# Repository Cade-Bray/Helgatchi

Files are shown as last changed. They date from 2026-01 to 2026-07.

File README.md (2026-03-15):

# Helgatchi
Handheld BLE + WiFi Hunter

## What is it?
A portable, hand-held BLE beacon and WiFi AP scanner/hunter, with built-in alerting, 1.69” full-color screen, and external SMA-RP antenna all powered by the XIAO ESP32-S3. 

The Helgatchi will passively scan for BLE devices and WiFi SSIDs/APs, and alert when specific Manufacturers, naming schemes, or services are discovered. 

It can be configured to alert anything you want, such as:
- Flock technology
- AXON technology
- Wearable health devices
- Any specific device
- Hidden WiFi/Bluetooth cameras

## Key Features
- Enclosed, portable, battery powered handheld rechargeable BLE and WiFi scanner and hunter that can live in your pocket.
- Passively scans for beacons in the background in-between sleeping, and actively scans when an alert is triggered.
- Powered by the XIAO ESP32-S3
- 6 RGB LEDs
- 1.69" rounded screen
- Vibration motor for alerts
- You can change
  - Color scheme
  - Alert settings
    - Vibrate
    - LEDs
    - Screen Wake
  - Scan settings
    - Sleep duration
    - Scan duration
  - Rules for alerts
    - MAC address (BLE, WiFi)
    - Manufacturer (BLE, WiFi OUI)
    - Device name (BLE name, WiFi SSID)
    - Service (BLE)

## Specifications

| Spec | Info 	|
|---	|---	|
| MCU 	| XIAO ESP32-S3 	|
| Flash 	| 8MB 	|
| Battery  	| 800mAh - 1200mAh 3.7v LiPo 	|
| Screen 	| Waveshare 1.69” LCD - 240p × 280p 	|
| Firmware 	| platform.io + Arduino 	|
| Software 	| Graphics: LVGL BLE: NimBLE LEDs: FastLED 	|
| Antenna  	| XIAO -> u.FL > back PCB > SMA-RP > 2.4Ghz antenna 	|
| Size 	| Width: 50mm Length: 80mm Height: TBD 	|

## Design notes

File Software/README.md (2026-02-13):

# Building and deploying (old code)
You will need
* VSCode
  * PlatformIO VSCode extension
* ESP32S3
* SPI connected screen

1. Clone the repository
2. Navigate into the `Helgatchi/Software/Helgatchi Core` directory
3. Initialize Platform.IO project (PIO -> Open Project -> Navigate to Helgatchi Core folder)
4. Build the code, will probably take a while to set up (Project tasts -> Build)
5. Build the filesystem (Project tasks -> Build Filesystem Image)
6. Plug in your ESP
7. Erase Flash
8. Upload Filesystem Image
9. Upload and Monitor

This should flash the ESP with filesystem and the code, and the serial monitor should output what the device is doing.

# Building and deploying (LVGL)
TODO

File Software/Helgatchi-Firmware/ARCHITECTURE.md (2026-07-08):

# Architecture

This document describes the firmware as it actually exists. The earlier
revision was design-only; this one tracks what's been built, the conventions
in use, and the footguns that have already cost real time.

---

## Big picture

```
                                 +---------------------+
        physical buttons ------> |                     |
        USB SOF / VSENSE  ------>|     HAL (g_hal)     |---> LCD (LovyanGFX)
        backlight / vibe / LEDs <|                     |---> WS2812 LEDs
                                 +---------------------+
                                            |
                                       posts EV_BTN_*, EV_UI_ACTIVITY
                                            v
                              +---------------------------+
                              |   EventBus (g_bus)        |
                              |   bounded queue, sub fan  |
                              +---------------------------+
                                /  |  |  |  |  |  |  |  \
                               v   v  v  v  v  v  v  v   v
                            settings, log, console, power, leds, vibe, ui, display

                          (each service: begin(), tick(), onEvent())
```

Every service has the same shape: a singleton `g_*`, a `begin(EventBus&)` that
subscribes and seeds state, a `tick()` called from `loop()`, and `onEvent()`
implementing `IEventHandler`. Exceptions are HAL (no event subscriptions to
the bus by default — it just exposes hardware) and SettingsService (storage).

---

## Services that exist today

### Implemented and stable
| Service | File | Role |
|---|---|---|
| `g_bus` | `event_bus.{h,cpp}` | Bounded FIFO + fan-out subscriber list. Mutex-protected. Tracks dispatch perf counters used by LogService. |
| `g_settings` | `settings_service.{h,cpp}` | NVS-backed key/value. **Auto-saves on every `CMD_SETTINGS_SET`.** Schema-versioned — bump `SCHEMA_VERSION` whenever a key's storage format or polarity changes; old NVS gets reset to defaults on next boot. |
| `g_hal` | `hal.{h,cpp}` | LCD (LovyanGFX), backlight (LEDC ch0), vibration motor (LEDC ch1, 20 kHz), WS2812 chain (FastLED), button polling, USB SOF detection, VSENSE ADC. |
| `g_logger` | `log_service.{h,cpp}` | Subscribes to all events, filters by `DebugLevel`. Hides/shows LVGL FPS overlay when level crosses RENDERING_PERF threshold. |
| `g_console` | `serial_console.{h,cpp}` | Line-based serial CLI. Commands: `settings`, `bus`, `stats`, `led`, `vibe`, `reboot`. Each character posts `EV_UI_ACTIVITY`. |
| `g_power` | `power_manager.{h,cpp}` | Sleep/wake decisions, battery sampling, scan/idle window timing, display state machine, shipping-mode RTC flag. |
| `g_leds` | `led_service.{h,cpp}` | LED pattern catalog (charging pulse, serial gradient, alert strobes). 30 FPS render with frame skip. Two-layer (ambient + alert) with 500ms fade. |
| `g_vibe` | `vibe_service.{h,cpp}` | Haptic pattern catalog. Step machine of `{intensity, duration_ms}` pairs. PWM via LEDC. Subscribed directly to `EV_BTN_*` so every button press fires a tick. |
| `g_ui` | `ui_controller.{h,cpp}` | Wraps LVGL: display init, keypad indev, focus groups, settings widget binding table. Calls `ui_init()` from SquareLine-generated code. |
| `g_display` | `display_service.{h,cpp}` | Debug status display (renders directly via LovyanGFX, separate from LVGL UI). Mostly historical. |

### Deferred / not yet implemented
- **Scanner Service** — BLE/WiFi scanning. Will subscribe to `CMD_SCAN_*`, post `EV_OBS_BATCH_READY`.
- **Parser / Enrichment / Entity Store** — observation pipeline.
- **Rule Engine** — pattern matching against entities.
- **Alert Manager** — owns alert lifecycle (raise/ack/snooze/clear).
- **Device Bridge (Public Mesh)** — outbound rule-fired broadcasts.
- **AppState** — central reducer for UI rendering. Currently the UI reads from `g_settings` and listens to events directly; AppState was deferred until there are more things to render.

The original architecture doc described all of these; they're stubs at most. Event IDs (`CMD_SCAN_*`, `EV_ENTITY_UPDATED`, `EV_RULE_TRIGGERED_LOCAL`, etc.) are defined in `include/event_ids.h` so the eventual services can be added without renaming.

---

## Event bus rules

- **Commands (`CMD_*`)** — imperative requests. Producers fire-and-forget; consumers may ignore.
- **Events (`EV_*`)** — facts about something that happened. Multiple subscribers OK.
- **Payloads** — fixed-size `EventPayload` union (`include/event_payload.h`). No heap, no pointers to externally-owned memory.
- **Direct service-to-service calls** are allowed only for read-only queries (e.g. `g_settings.getBool(...)`, `g_hal.usbAttached()`) and for hardware control where the bus would add too much latency (e.g. `g_vibe.play()` from UI for tactile feedback, `g_hal.writeLEDFrame()` from LedService).
- **Auto-save on `CMD_SETTINGS_SET`** — SettingsService persists to NVS on every value change. Currently fine because all bound widgets are switches/dropdowns (settle once per user action). If a slider gets bound, add a debounce — `lv_slider`'s `LV_EVENT_VALUE_CHANGED` fires per drag step.

---

## UI: built in SquareLine Studio, wired in C

The screens are designed in **SquareLine Studio** (`Helgatchi-UI` SLS project, version 1.6.0, targeting LVGL 9.3 + Arduino+TFT_eSPI export). Exported files land in `src/UI/`. Things to know:

- **Don't edit `src/UI/*` by hand** — re-export overwrites them. All custom logic lives in `ui_controller.cpp`.
- **`ui_init()`** (in `src/UI/ui.c`) builds all screens and loads the splash. UIController calls it from `begin()`.
- **Lowercase names** — the project is set to "Force exported names to lower case", so widgets are `ui_<screen>_<type>_<name>` all lowercase.
- **Top bar** is a Component (purple in the SLS hierarchy), instanced on Status / Menu / Settings. Three labels per instance: left status, centre title, right battery %. The right label is updated by `_refreshBatteryLabels()` on `EV_BATTERY_UPDATED`.
- **Settings widgets are bound table-driven**: `_bindings[]` in `ui_controller.cpp` maps each SLS widget pointer to a `SettingsKey`. A polymorphic `_readWidget` / `_writeWidget` handles switch / dropdown / slider / arc / roller / checkbox. To add a new setting widget: one line in the table (assuming it maps 1:1 to an SKEY).
- **Custom (non-1:1) bindings**: BLE+WiFi switches combine into `SKEY_SCAN_MODE` via bit-OR, wired directly. Same shape works for any future "two switches → one bit-packed setting" case.
- **Action buttons** use a parallel `_actions[]` table mapping widget → `EventId`. The Reboot button now posts `CMD_POWER_REBOOT` like the other power buttons (it used to call `ESP.restart()` directly and skip teardown); PowerManager owns the teardown — `g_vibe.stop()` + `HAL::prepareForReboot()` — then `ESP.restart()`.

### Keypad input convention
- Physical buttons → `EV_BTN_*` → UIController converts to LVGL keys via a small queue (press/release pair per button event).
- **Navigation mode** (default): `LEFT` / `RIGHT` send `LV_KEY_PREV` / `LV_KEY_NEXT` to walk the focus group. **Don't send `LV_KEY_LEFT/RIGHT` for navigation** — focused switches interpret those as direct toggle and you'll never get past the first one.
- **Edit mode** (after `LV_KEY_ENTER` on a slider/dropdown): `LEFT` / `RIGHT` send `LV_KEY_LEFT/RIGHT` to the focused widget.
- **Dropdown open** (`lv_dropdown_is_open(focused)` returns true): `LEFT` / `RIGHT` send `LV_KEY_UP/DOWN` because dropdowns navigate options that way.
- **CENTER short** = `LV_KEY_ENTER`, except on Status it's a global "open Menu" shortcut.
- **CENTER long** = panic-out to Status from any non-Status screen.
- **Group population** is done via `_populateGroupFromSubtree` — recursively walks the screen and adds anything `lv_obj_check_type` recognises as interactive (switch, checkbox, dropdown, roller, slider, arc, button) to the group in DOM order.

### Settings polarity convention
- All sleep-inhibit settings use **positive form**: `TRUE = allow sleep`. Keeps the SLS switch ON/OFF labels intuitive.
- Examples: `SKEY_DEBUG_SLEEP_WITH_SERIAL` (true = allow sleep with serial open), `SKEY_SLEEP_WHILE_USB` (true = allow sleep when USB attached). Inhibit logic in `_isInhibited()` inverts: `!_sleep_w_serial` and `!_sleep_while_usb`.

### Display state machine
PowerManager owns three display states (`DisplayState::OFF/ON/DIM`):
- `OFF` → backlight off, `g_ui.setRenderEnabled(false)`. Used for silent TIMER-wake scan windows and pre-deep-sleep teardown.
- `ON` → user's stored brightness, render enabled.
- `DIM` → `SCREEN_BRIGHTNESS_MIN` PWM, render enabled. Triggered when ≤5 s remain in the interactive timeout.

`setRenderEnabled(false)` skips `lv_timer_handler()` entirely — saves ~70 % CPU during silent scans (LVGL is the heaviest thing in the loop). On wake-from-sleep transitions to ON/DIM, PowerManager also calls `g_logger.applyPerfMonitor()` to re-sync the LVGL FPS overlay against the current debug level (LVGL auto-shows it at `lv_display_create` and someone has to actively re-hide it if the user isn't at PERF level).

---

## Power model

| Wake cause | `_user_active` | Display | Sleep timer | Boot indicator (LED + haptic) |
|---|---|---|---|---|
| Cold boot (`ESP_RST_POWERON`) | true | ON | 15-20s interactive | yes |
| EXT1 wake (button) from sleep | true | ON | 15-20s interactive | yes |
| TIMER wake (autonomous scan) | false | OFF | 5s scan-then-sleep | no (silent) |
| Software reset (`ESP.restart`) | true | ON | 15-20s interactive | **no** — the user just clicked Reboot, a second indicator on the other side feels like one long buzz |
| Shipping mode wake | requires 2 s CENTER hold to confirm; otherwise re-sleeps | OFF→ON after confirm | normal | no |

Sleep entry calls `prepareForSleep()` which does:
1. `g_hal.clearLEDs()` — must run **before** prepareForSleep takes the LED data pin away from RMT.
2. `_tft.sleep()` — LCD controller into sleep, drops to ~50 µA.
3. Detach LEDC from backlight pin, drive LOW, lock the pad with `gpio_hold_en` (and same for LED data pin).
4. `gpio_deep_sleep_hold_en()` — honour pad locks during deep sleep.

`HAL::begin()` releases those holds at the start so peripherals can reinit. **Don't add a new pad-held GPIO without releasing it in `begin()`** — it'll stay locked low forever after the first sleep cycle.

Deep sleep wakes only via EXT1 on `PIN_BTN_1` (GPIO6 — the only RTC-capable button pin; GPIO43/`PIN_BTN_2` is readable but can't be a wake source). GPIO6 goes low on left OR center, so any of those wakes the chip. On the next boot `PowerManager::checkWakeHoldOrResleep()` (the very first thing in `setup()` after Serial.begin) requires the user to hold CENTER — both `PIN_BTN_1` and `PIN_BTN_2` LOW — for the hold window (`SLEEP_WAKE_HOLD_MS` 1.5 s for regular sleep, `SHIPPING_WAKE_HOLD_MS` 2.5 s for shipping — a more deliberate unbox gesture). If the hold isn't satisfied it re-enters the same sleep it came from: shipping (`_shipping_pending`, EXT1 only) or regular (EXT1 + the scan-cycle timer stashed in `_deep_sleep_timer_us`). Timer wakes and cold boots skip the check. This makes pocket carry reliable — nothing but a deliberate center hold wakes the device.

---

## Footguns & lessons

These all cost real time. Read before re-treading:

### LVGL config + library caching
- **Use both `lv_conf.h` AND `-D` build_flags** for any LVGL feature that's conditionally compiled in a `.c` file (fonts, sysmon, optional widgets). PIO doesn't always notice that a header changed and rebuild the LVGL `.a`; the `-D` flag is what reliably forces it.
- **`LV_CONF_PATH` is required** in `platformio.ini` because LovyanGFX ships an example `lv_conf.h` at `examples/Advanced/LVGL_PlatformIO/src/lv_conf.h` that PlatformIO's recursive include scan finds before ours. The absolute-path `LV_CONF_PATH=\"$PROJECT_DIR/include/lv_conf.h\"` bypasses include-path search entirely.
- **`LV_TICK_CUSTOM` was removed in LVGL 9.x.** Register a tick callback with `lv_tick_set_cb(my_tick_cb)` instead — without it, animations and delays never advance even though `lv_timer_handler` is being called.
- **`LV_USE_PERF_MONITOR` auto-shows the overlay** in `lv_display_create()` ([lv_display.c:185](.pio/libdeps/seeed_xiao_esp32s3/lvgl/src/display/lv_display.c#L185)). Calling `lv_sysmon_hide_performance` after it doesn't invalidate the screen area, so the pixels stay until something else triggers a redraw — call `lv_obj_invalidate(lv_screen_active())` after toggling.

### GPIO / hardware
- **PIN_SPI_BL (GPIO3)** is a strapping pin with internal pull-up enabled by ROM. Without explicit `gpio_hold_en`, the backlight comes back on as soon as LEDC powers down at deep-sleep entry. Keep the pad held LOW through sleep.
- **PIN_LED_DATA (GPIO2)** floats through long sleeps and EMI/noise can be interpreted by WS2812s as data — observed as a single white flash on next wake. Same fix: hold the pad LOW with `gpio_hold_en`.
- **ERM vibration motors won't spin below ~150 PWM duty** (~2 V average across the motor). Anything lower whines audibly without producing tactile feedback. The "minor" feel of `HAPTIC_TICK_LIGHT` comes from a *short* duration at high duty, not a low duty cycle.
- **USB SOF detection window must be ≥100 ms.** Hosts pause SOFs occasionally (heavy traffic, brief suspends). The original 2 ms window flickered `_usb_attached` to false often enough to break sleep inhibition.
- **Boot LED flash must be skipped on TIMER wake AND on software resets.** Otherwise scan windows light up the device, and pressing Reboot gives two haptics back-to-back across the reset gap. Gate on `esp_reset_reason()` + `esp_sleep_get_wakeup_cause()`.

### SquareLine Studio
- **Re-export overwrites `src/UI/` entirely.** Don't edit those files. All bindings/wiring lives in `ui_controller.cpp`.
- **Lowercase names mode** is enabled in this project's SLS settings. Any expected widget pointer is `ui_<screen>_<type>_<name>` lowercase.
- **Dropdown options must be in enum order.** SLS stores them as a `\n`-separated string; the index is what gets stored. We've eaten this bug twice (Debug Level had an extra "Off" once; brightness slider had range 50..255 instead of enum 0..3).
- **The screen object pointers (`ui_screen_*`) become NULL after `screen_destroy`.** Don't hold pointers to widgets across screen destroys; iterate the SLS-exported globals each time.
- **SLS's auto-generated `ui_helpers.c` references many widget APIs** (slider, dropdown, roller, etc.) even if you don't use them. Either enable those `LV_USE_*` widgets in `lv_conf.h` (linker DCE strips unused ones anyway) or accept implicit-declaration warnings.

### Settings / NVS
- **Schema bumps reset NVS** — every `SCHEMA_VERSION` increment loses user-saved settings. Necessary when a key's *meaning* changes (polarity flip, enum size change) but annoying. Try to add new keys without re-purposing existing ones.
- **`s_key_mask` table in `settings_service.cpp` MUST stay in sync with `SettingsKey` enum order.** No static_assert for size, so a missing entry shifts every subsequent mask wrong without compile error. Counter-example: `s_key_name` in `serial_console.cpp` *does* have a static_assert and caught a real bug (NO_SLEEP_WHILE_CHARGING was silently misaligned).

### Debug levels
- `DEBUG_INFORMATIONAL` (0) — only state changes (sleep, scan, settings, alerts). Sleep-countdown logged only when ≤5 s remain.
- `DEBUG_HIGH` (1) — INFO + UI activity, button presses, battery, every countdown tick.
- `DEBUG_RENDERING_PERF` (2) — suppresses event firehose, emits one perf summary line/sec, shows LVGL FPS+CPU overlay.
- `DEBUG_SCANNING_PERF` (3) — placeholder; treated as RENDERING_PERF until scanner work begins.

PERF level "events processed" counter is from `g_bus.perfSnapshotAndReset()` — measures dispatch wall-clock including subscriber `onEvent()` time, so a slow handler shows up here.

---

## Pin map (from `include/hal.h` + `GPIO.md`)

| GPIO | Use | Notes |
|---|---|---|
| 1 | SPI_DC (LCD) | LovyanGFX-managed |
| 2 | LED_DATA (WS2812 ×6) | Held LOW through deep sleep |
| 3 | SPI_BL (backlight PWM) | LEDC ch0, 5 kHz, held LOW through sleep, strapping pin |
| 4 | VIBRATE | LEDC ch1, 20 kHz (above audible). Low-side N-MOS gate, 100 kΩ pull-down. |
| 5 | VSENSE | ADC, voltage divider /2 (VBATT 3.0–4.2 V → 1.5–2.1 V) |
| 6 | BTN_1 (matrix line A) | RTC-capable, used for EXT1 wake |
| 7 | SPI_SCK | LovyanGFX |
| 8 | SPI_RST | LovyanGFX |
| 9 | SPI_MOSI | LovyanGFX |
| 43 | BTN_2 (matrix line B) | NOT RTC-capable |
| 44 | SPI_CS | LovyanGFX |

Buttons are a 2×2 diode matrix: GPIO6 LOW only = LEFT, GPIO43 LOW only = RIGHT, both LOW = CENTER. EXT1 wake is configured for GPIO6 alone (covers all buttons via the diode matrix).

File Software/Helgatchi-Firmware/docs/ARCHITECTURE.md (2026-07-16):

# Architecture

Quick map of the firmware. For per-phase implementation history see the
other docs in this directory; for current next-up work see `PHASE_6_SCAN_ENGINE.md`.

## Hardware

- **MCU**: ESP32-S3 (Seeed XIAO ESP32-S3 module)
- **Flash**: 8 MB
- **PSRAM**: 8 MB (LVGL framebuffers + LVGL allocator pool + scan ring + seen-devices map)
- **Display**: ST7789 SPI panel @ 80 MHz, 280×240 (no TE pin — frame tearing
  inherent above ~30 fps animation)
- **Radios**: BLE + WiFi (NimBLE for BLE, ESP32 WiFi for scan)
- **LEDs**: addressable WS2812 chain via FastLED
- **Motor**: PWM-driven haptic
- **Buttons**: left / right / center (debounced in `HalService`)
- **Battery**: VSENSE via ADC, USB-attach detect via SOF, charge-state inferred
- **Power**: deep-sleep wake via EXT1 on center button + RTC timer for scheduled scan windows; shipping mode for cold storage

## Build system

PlatformIO, Arduino-ESP32 framework. Three pre-scripts run before each
build (see `platformio.ini`):

1. `scripts/auto_montserrat.py` — scans source for referenced LVGL Montserrat
   font sizes and `-D`s them into the build.
2. `scripts/build_info.py` — emits `include/build_info.h` with build date and
   UI version (mtime of `Helgatchi UI.eez-project`).
3. `scripts/build_vendor_tables.py` — generates `include/vendor_tables_data.h`
   (~700 KB of flash data) from `scripts/vendor_sources/oui.csv.gz` and
   `scripts/vendor_sources/bt_companies.yaml`. Run
   `scripts/refresh_vendor_sources.py` manually to update the upstream cache.

Partition layout (`partitions.csv`): NVS 28 KB / factory 5 MB / spiffs ~3 MB
(LittleFS-formatted; partition subtype is `spiffs` because that's what
esptool/PIO look for, but the on-disk format is LittleFS via
`board_build.filesystem = littlefs`).

## Service model

Every subsystem is a `class FooService { void begin(EventBus&); void tick(); ... };`
with a single global instance (`extern FooService g_foo;`). `setup()` in
`main.cpp` initializes them in a specific order (some have prerequisites —
e.g. `g_rules` depends on `g_scan_service` and `g_alerts` being ready, and on LittleFS
being mounted).

Service catalog (`src/main.cpp` shows current init order):

| service | role |
|---|---|
| `g_bus` | Pub/sub event bus (queued; drained per main-loop tick) |
| `g_settings` | NVS-backed settings store (`SettingsKey` enum + `SKEY_*` macros) |
| `g_hal` | Display, LEDs, motor, buttons, ADC |
| `g_logger` | LVGL perf overlay gating, serial debug-level filtering |
| `g_console` | Serial command parser |
| `g_power` | Scan/sleep cycle, battery sampling, shipping mode |
| `g_alerts` | Active alert store (RTC slow memory persistence across deep sleep) |
| `g_scan_service` | Scan-result ring buffer (256) + seen-devices map (128). Both in PSRAM |
| `g_rules` | Rules engine — loads `/rules/{factory,user}/*.json`, drains `g_scan_service`  |
| `g_leds` | LED pattern renderer (~30 fps), pattern name registry |
| `g_vibe` | Haptic step-machine, pattern name registry |
| `g_ui` | LVGL `lv_timer_handler` wrapper, render gating when screen off |
| `g_display` | Top-bar icon strings (battery / USB / BT / WiFi / bell) |
| `g_settings_screen` | Settings widget wiring (EEZ-generated UI) |
| `g_alerts_screen` | Alert card UI (lives in its own file mirroring settings_service split)|

## Event bus

`include/event_ids.h` is the source of truth for event IDs. Two flavors:

- `CMD_*` — imperative requests (`CMD_SCAN_START`, `CMD_ALERT_ACK`, etc.)
- `EV_*` — immutable facts (`EV_ALERT_RAISED`, `EV_BATTERY_UPDATED`, etc.)

Payloads are an 8-byte tagged union (`include/event_payload.h`). Adding a new
event ID *to send a custom payload* means extending the union.

**Hot path note**: scan results do NOT go through the bus. `g_scan_service.publish()`
writes to a PSRAM ring buffer; `g_rules.tick()` drains it directly via
`g_scan_service.drain()`. Only the alert path that fires *after* matching emits bus
events (downstream of the hot loop).

## Storage tiers

| tier | what lives here |
|---|---|
| Flash (app) | Firmware, generated vendor tables, factory rule JSONs (via LittleFS image at build time) |
| NVS | Settings (`g_settings`), rule enable/disable overlay |
| RTC slow memory  | Active alerts (`g_alerts`) — survives deep sleep, cleared on cold boot |
| LittleFS | `/rules/factory/*.json` (read-only at runtime), `/rules/user/*.json` (writable) |
| PSRAM | LVGL framebuffers + LVGL allocator pool, scan ring + seen-devices map |
| Internal SRAM | Stack, FreeRTOS, hot in-flight data only |

## Conventions

- **Singular/plural serial verbs**: `setting`/`settings`, `alert`/`alerts`,
  `led`/`leds`, `rule`/`rules`. Singular mutates one thing; plural lists or
  manages many.
- **Underscore-as-space in serial values**: multi-word titles in `alert` and
  `rule create` use underscores (`title=Axon_device_nearby`). Other fields
  (vibe, led, type, action, etc.) take registry names verbatim.
- **Comma-separated arrays in rule criteria**: `rule add foo mfg=0x05D2,0x004C`
  adds two atomic criteria. `oui_org_contains` and `mfg_org_contains` expand
  at parse time into many atomic criteria by walking the vendor table.
- **Per-(rule, MAC) dedup**: alerts use identifier format
  `<rule_name>:<MAC_hex>` so re-firing on the same device updates last_seen
  rather than stacking new alerts.
- **Factory rule immutability**: `_rules[i].is_factory == true` blocks all
  content mutations. Only `enable`/`disable` works on factory rules, persisted
  via NVS overlay (survives FS reflash).

## Debugging / introspection commands

- `stats` — uptime, chip, memory, display fps, bus drops
- `scan` — list seen devices (dedup'd by MAC)
- `scan inject domain=... mac=... mfg=... name=...` — synthesize a scan
  result for testing the rules engine without real radio
- `vendor oui <AA:BB:CC>` / `vendor mfg <0xNNNN>` — forward lookup
- `vendor search <substr>` — list every IEEE org + BT SIG name containing the
  substring (same code path RulesService takes at rule load for `*_org_contains`)
- `rules` — list all rules with their full criteria (so `rule rm <name> <idx>`
  is unambiguous)
- `rules show <name>` / `rules stats` / `rules reload`
- `selftest` — GPIO short/load detection

## Things that have already burned us

- **DMA + PSRAM**: cache writeback needed before LovyanGFX flushes from PSRAM.
  See the `Cache_WriteBack_Addr` call in `ui_controller.cpp` flush_cb.
- **NimBLE timing**: not in the codebase yet (Phase 6), but historically
  `NimBLEDevice::init` on Arduino-ESP32 must come after WiFi init if both
  share radio coex.
- **LittleFS unlink while iterating**: the directory iterator holds FDs on
  entries — collect paths first, close the dir, then unlink.
- **Partition table changes** wipe NVS (and reformat LittleFS if the
  partition moves). Avoid changing offsets once stable.
- **ArduinoJson 7** allocates dynamically; on big rule files use stack-scoped
  `JsonDocument` to avoid leaks.

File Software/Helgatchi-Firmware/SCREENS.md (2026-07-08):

# Screens

This document describes the actual UI screens, their SquareLine Studio
implementation, and the wiring between SLS-exported widgets and firmware
behavior. The earlier revision was a design intent — this one tracks what
exists, what doesn't, and the conventions in use.

---

## Source of truth

- **SLS project** (external): `Helgatchi-UI`, SLS 1.6.0, targeting LVGL 9.3, "Arduino with TFT_eSPI" board template, "Force exported names to lower case" enabled, "Custom variable prefix" `uic`.
- **Exported files**: `src/UI/*.{c,h}` — *do not edit by hand, re-export overwrites.*
- **Firmware wiring**: `src/ui_controller.cpp`. All buttons / settings / battery / dim / haptic hooks live here.

Whenever the SLS project is re-exported, widget pointer names may change. The compiler will catch most of these as undeclared identifiers in `_bindings[]` / `_actions[]` / batteryLabels[] in `ui_controller.cpp`.

---

## Screens that exist today

| # | Screen | SLS object | Status |
|---|---|---|---|
| 1 | Splash | `ui_screen_splash_screen` | ✅ Implemented |
| 2 | Status | `ui_screen_status_screen` | ✅ Renders top bar, no body content yet |
| 3 | Menu | `ui_screen_menu_screen` | ✅ Horizontal carousel, only Settings panel exists |
| 4 | Settings | `ui_screen_settings_screen` | ✅ Most-developed screen — actual settings widgets bound to NVS |

Screens deferred to later milestones: **Scan, Devices, Device Detail, Rules, Alerts, About**. Each will follow the same pattern as Settings (top bar component + content panel + binding table).

---

## Top bar component

Built once in SLS as a Component, instanced on Status / Menu / Settings (purple in the Hierarchy panel — they share the same Component definition and update together if edited).

Three labels per instance, named consistently across screens:
- `top_bar_left_text` — left-side status indicator (currently shows "zzz" placeholder on Menu, free text per screen)
- `top_bar_center_text` — screen title
- `top_bar_right_text` — battery percentage

The right-text labels are tracked in `_batteryLabels[]` in `ui_controller.cpp`. On `EV_BATTERY_UPDATED` they all get rewritten with the formatted percentage / "CHRG" / "FULL" / "??". A cached `_last_batt_*` is also re-applied when a screen loads, so a freshly-loaded screen paints immediately instead of waiting up to 30 s for the next battery sample.

To add the top bar to a new screen: drop the Component instance in SLS → re-export → add the new screen's `top_bar_right_text_*` pointer to `_batteryLabels[]`.

---

## Splash → Status

The splash → status transition is **defined in SLS itself**, not in C:
- Trigger: `LV_EVENT_SCREEN_LOADED` on splash
- Action: `Change Screen` to Status with `FADE_OUT`, 500 ms, **3000 ms delay**

The C side just calls `ui_init()` (loads splash) and lets LVGL handle the rest. This is the canonical SLS pattern — when something can be a CLICKED-event-driven screen change, prefer doing it in SLS.

The 3 second delay needs `lv_tick_set_cb(_tick_cb)` to be registered (LVGL 9.x removed `LV_TICK_CUSTOM`, so without this the delay never elapses). `UIController::begin()` does this before `lv_display_create`.

---

## Menu screen

Horizontal scroll-snap carousel (`ui_menu_screen_container_container5`). Each child panel is one menu entry. Currently only `panel_settings_pannel` (sic — SLS-generated typo) exists, with `lv_image_settings_image`, label, and a `Clicked → Change Screen → Settings` event defined in SLS.

Keypad navigation: `_grp_menu` is populated by iterating the carousel container's children, so adding a new menu panel in SLS (Devices, Rules, Alerts, etc.) auto-shows up in the focus cycle without code changes. LVGL's group focus auto-scrolls the snap container.

Adding a new menu entry:
1. In SLS: copy the Settings panel inside `container_container5`, rename, give it its own `Clicked → Change Screen → <target>` event
2. Re-export
3. (No C change needed for the menu screen itself)
4. Build / register the target screen separately

---

## Settings screen

The most-developed screen — every other future screen will follow this pattern.

### Layout
A top bar + a vertical scrollable panel (`panel_panel2`) of section labels and option containers. Each option container has a label and one widget (switch/dropdown/slider/button).

### Bound settings (`_bindings[]` in `ui_controller.cpp`)

Each entry is `{ &ui_<widget>, SKEY_<X> }` — the polymorphic `_readWidget` / `_writeWidget` handles the widget type at runtime, so a switch, dropdown, slider, etc. all work via the same path.

Currently bound:
| Widget | SLS pointer | SettingsKey |
|---|---|---|
| Brightness dropdown | `ui_settings_screen_dropdown_brightness` | `SKEY_SCREEN_BRIGHTNESS` |
| Performance Mode dropdown | `ui_settings_screen_dropdown_performance_mode` | `SKEY_PERF_MODE` |
| Debug over Serial switch | `ui_settings_screen_switch_debug_over_serial` | `SKEY_DEBUG_SERIAL_ENABLED` |
| Debug Level dropdown | `ui_settings_screen_dropdown_debug_level` | `SKEY_DEBUG_LEVEL` |
| Sleep with Serial switch | `ui_settings_screen_switch_sleep_while_serial` | `SKEY_DEBUG_SLEEP_WITH_SERIAL` |
| Sleep with USB switch | `ui_settings_screen_switch_sleep_while_usb` | `SKEY_SLEEP_WHILE_USB` |

### Custom (non-1:1) bindings

Some widgets don't map directly to a single SKEY:
- **BLE / WiFi scanning switches** combine into `SKEY_SCAN_MODE` via bit-OR (BLE = bit 0, WiFi = bit 1). Custom `_onScanBitsChanged` rebuilds the combined value from both switch states on any change. `_refreshScanBits()` in the other direction.
- **Reboot button** (`reboot_button`): `_on_reboot_button` posts `CMD_POWER_REBOOT`; PowerManager tears down peripherals (`g_vibe.stop()` + `HAL::prepareForReboot()`) before `ESP.restart()`. (Was a bare `ESP.restart()` that skipped teardown and could leave the motor buzzing through the boot window.)

### Action buttons (`_actions[]`)

Buttons that fire one-shot commands. Currently:
| Button | Command |
|---|---|
| `button_shipping_mode` | `CMD_POWER_SHIPPING_SLEEP` |
| `button_sleep` | `CMD_POWER_SLEEP` (bypasses inhibit by design — Sleep Now button) |

### Sleep countdown text

`ui_settings_screen_label_sleep_text` displays the live sleep countdown. Updated on `EV_SLEEP_COUNTDOWN_UPDATED`:
- `0xFFFF` (sentinel from PowerManager when inhibited) → `"Will not sleep"`
- otherwise → `"Sleep in Ns"`

### Dropdown options must match the enum
SLS stores dropdown options as a `\n`-separated string and saves the index. **The index is the value stored in NVS.** If your dropdown options aren't in enum order, you'll silently store wrong values — we've eaten this bug twice (extra "Off" leading the Debug Level dropdown, slider range 50..255 vs enum 0..3 for brightness).

Current required option strings:
- Brightness: `Min\nLow\nMedium\nHigh\nMax` (matches `ScreenBrightness` enum)
- Performance Mode: `Performance\nBalanced\nPower Saver` (matches `PerfMode` enum, missing DYNAMIC by intent)
- Debug Level: `Info\nHigh\nRender\nScan\nPerf\nTeleplot` (index = `DebugLevel` enum value, 1:1). Perf = human-readable telemetry, Teleplot = `>k:v` graphing stream.

---

## Keypad input contract

UIController converts physical button events into LVGL keys with these conventions:

| Action | Default (nav mode) | In edit mode | Dropdown open |
|---|---|---|---|
| LEFT | `LV_KEY_PREV` (prev focused widget) | `LV_KEY_LEFT` (decrement value) | `LV_KEY_UP` (prev option) |
| RIGHT | `LV_KEY_NEXT` (next focused widget) | `LV_KEY_RIGHT` (increment value) | `LV_KEY_DOWN` (next option) |
| CENTER short on Status | open Menu (direct screen change, bypasses LVGL) | — | — |
| CENTER short elsewhere | `LV_KEY_ENTER` | `LV_KEY_ENTER` (commit edit) | `LV_KEY_ENTER` (select option) |
| CENTER long | back to Status (panic-out) | — | — |

**Common mistakes**:
- Sending `LV_KEY_LEFT/RIGHT` for navigation. Switches interpret those as direct toggle and you'll never get past the first switch in the focus group.
- Forgetting that `lv_dropdown_is_open()` is widget-local state, not group editing state. `lv_group_get_editing()` returns false even with a dropdown list visible. Both checks needed.

### Group population
`_populateGroupFromSubtree()` recursively walks a screen's widget tree and adds anything `lv_obj_check_type` recognises as interactive (switch, checkbox, dropdown, roller, slider, arc, button) to the group **in DOM order**. So the focus cycle matches the order children appear in SLS's Hierarchy panel — drag widgets there to reorder navigation.

---

## Screen lifecycle hooks

`_scr_evt_cb` (registered for all four screens via `_registerScreenLogging`) handles three things on every screen transition:

1. **Logging** — `[t] SCREEN_LOAD_START / LOADED / UNLOAD_START / UNLOADED  <name>` to serial when debug serial is on.
2. **Group switching** — on `LV_EVENT_SCREEN_LOAD_START`, set the keypad indev's group to the screen's group (or NULL for splash/status).
3. **Settings refresh** — on Settings screen load, repaint widget values from `g_settings`.

Plus battery label re-paint (`_refreshBatteryLabels`) on every screen-load so the right-text shows the latest reading immediately.

---

## What's not implemented

- **Scan screen** — needs to surface scan state, lock-on, scan mode toggle. Future commands: `CMD_SCAN_START`, `CMD_SCAN_STOP`, `CMD_SCAN_LOCKON_START/STOP`. Will subscribe to `EV_SCAN_STATE_CHANGED` for the toggle status.
- **Devices screen** — paged list. Needs Entity Store + AppState before this is meaningful. Pagination + per-row rendering will be the main UI work.
- **Device Detail screen** — view one entity, optionally `CMD_RULE_ADD_CUSTOM` from it.
- **Rules screen** — toggle rule packs (`CMD_RULE_PACK_ENABLE/DISABLE`), wipe customs.
- **Alerts screen** — list active + history, ack (`CMD_ALERT_ACK`) / snooze (`CMD_ALERT_SNOOZE`).
- **About screen** — firmware version, build info, ruleset version.

The pattern for each is identical to Settings: SLS top-bar instance + content layout + add the appropriate widgets to either `_bindings[]` (state) or `_actions[]` (commands). Screen-load hook for any data that needs paint-on-entry.

---

## Cross-cutting

### `EV_UI_ACTIVITY` is used as the activity heartbeat
Every button press posts it. Every character typed in the serial console posts it. PowerManager updates `_last_activity_ms` and forces display ON. If a future input source (touch, gesture) is added, fire `EV_UI_ACTIVITY` from there too.

### Render is gated by display state
`UIController::tick()` is a no-op when `_render_enabled` is false. PowerManager flips it from `_setDisplay`: `OFF → false`, `ON/DIM → true`. This saves ~70 % CPU during silent TIMER-wake scan windows.

### LVGL FPS overlay
Compiled in via `LV_USE_PERF_MONITOR=1`, but visibility is runtime-toggled by `LogService::applyPerfMonitor()` based on `DebugLevel`. Reapplied on:
- After `g_ui.begin()` (display-create auto-shows the overlay; we have to actively re-hide if level < PERF)
- On every `EV_SETTINGS_CHANGED` that crosses the PERF threshold
- On `_setDisplay(ON/DIM)` (covers wake-from-silent-scan transitions)

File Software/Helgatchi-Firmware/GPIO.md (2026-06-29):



# GPIO Assignments

* GPIO1 - SPI_DC
* GPIO2 - LED data x6 LEDs
* GPIO3 - SPI_BL
* GPIO4 - Vibration control
* GPIO5 - VSENSE
  * 
* GPIO6 - BUTTONS 1
* GPIO43 - BUTTONS 2
  * 
* GPIO44 - SPI_CS
* GPIO07 - SPI_SCK
* GPIO8 - SPI_RES
* GPIO9 - SPI_MOSI

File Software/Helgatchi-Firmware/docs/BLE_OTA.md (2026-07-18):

# BLE OTA — passive peer-to-peer firmware updates

**Status: design only. Nothing here is implemented yet.** This doc captures the
target architecture so the partition, transport, and security decisions are
settled before code lands.

Goal: an admin-mode Helgatchi passively broadcasts "I can update you." Nearby
devices notice, check the offer against their own version + policy, ask the user,
then pull the image over BLE, verify it, and (with a second confirmation) swap to
it and reboot. No servers, no cables, no central app — one seeded device
propagates to the swarm in the field.

The offerer distributes **its own running firmware** — see [Self-clone
constraint](#self-clone-constraint). It is not a general file server.

---

## Security decision — settle this first

BLE OTA from any sender is a wireless brick/backdoor vector. Two independent
layers, and the doc assumes both:

1. **Offer authenticity (who is allowed to offer).** The discovery advert is
   HMAC-signed exactly like admin frames (`AdminService` / `admin_protocol`,
   shared `HELGATCHI_HMAC_SECRET`). A receiver won't even *prompt* on an
   unsigned/forged offer. This reuses existing infra but is **symmetric** — the
   secret is on every device, so it authenticates "a legit unit is offering,"
   not "this exact image is trustworthy." Extract the secret from one unit (no
   flash encryption yet) and offers can be forged.

2. **Image authenticity (what is allowed to boot).** The real gate. The image
   carries an **asymmetric signature** (private key never on any device); the
   receiver verifies it before install, and ideally the bootloader re-verifies
   at boot. This is **Secure Boot v2** (RSA-3072 or ECDSA over SHA-256) +
   flash encryption. With it, a tampered/unsigned image is rejected regardless
   of who sent it, and peer-to-peer cloning is safe by construction. It also
   retroactively hardens the admin HMAC secret against extraction.

> **Open decision:** ship BLE OTA *only* with Secure Boot v2 enabled? Strongly
> recommended. Until then, the app-level signature check (below) is integrity +
> weak authenticity, not a real trust anchor. Enabling secure boot is a one-way
> eFuse burn and complicates dev flashing — decide before the first signed
> release, because you can't retrofit it onto already-fielded units.

MD5 (per the flow below) covers **integrity** — it detects corruption in
transit. It is not a security control. Keep it for cheap chunk/whole-image
validation; rely on the signature for trust.

---

## Partition layout change (prerequisite)

Today: single `factory` app (5 MB) + oversized `spiffs` (~3 MB, ~empty — the
vendor tables live in the app image, not the FS). OTA needs two equal app slots.
The wasted FS space pays for the second slot.

```
# OTA-capable layout (8 MB). A/B app slots + small FS.
# Name,   Type, SubType, Offset,    Size,      Flags
nvs,      data, nvs,     0x9000,    0x5000,
otadata,  data, ota,     0xe000,    0x2000,
ota_0,    app,  ota_0,   0x10000,   0x3A0000,   # 3.625 MB
ota_1,    app,  ota_1,   0x3B0000,  0x3A0000,   # 3.625 MB
spiffs,   data, spiffs,  0x750000,  0xB0000,    # 704 KB
```

- Each slot **3.625 MB** vs the current ~3.32 MB image → ~480 KB headroom.
  Watch it: the app is actively growing, and an image that exceeds slot size
  can't OTA (fails safe — no brick — but forces a serial reflash + repartition).
- No `factory` partition: pure A/B. Patient-zero's first image is serial-flashed
  to `ota_0`.
- `nvs` shrinks 28→20 KB to fit `otadata` before the 64 KB app boundary (20 KB
  is ample). To keep 28 KB instead, push `ota_0` to `0x20000` and eat a 56 KB
  alignment gap.
- **Switching tables wipes NVS** — one-time settings reset (same warning already
  in `partitions.csv`).
- Update the layout note in `docs/ARCHITECTURE.md` when this lands.

### Self-clone constraint

The offerer streams a copy of its **own active app partition**
(`esp_partition_read` from the running `ota_X`; hash via
`esp_partition_get_sha256`). It cannot store and forward an arbitrary image —
the 704 KB FS can't hold a 3.3 MB payload. Consequence: an offerer only ever
distributes the firmware it is itself running. To seed a new version, one device
first gets it via serial / Web-Bluetooth, then becomes an offerer.

---

## Roles

| Role | Who | BLE posture |
|---|---|---|
| **Offerer**  | a device in **admin mode** | broadcasts a signed OTA-offer advert; runs a connectable GATT server that serves its own active partition |
| **Receiver** | any device, OTA-enabled | observes offers via the scan engine; connects as GATT client and pulls the image |

Multiple offerers may broadcast at once. A receiver picks one (highest offered
version; tie-break on RSSI) and ignores the rest for the duration of a transfer.

---

## End-to-end flow

```
OFFERER (admin)                         RECEIVER (OTA enabled)
──────────────                          ──────────────────────
broadcast OTA-offer advert  ───────▶    scan engine filters offer into a queue
  {type, fw_version, HMAC}              authenticate HMAC ─ forged? drop, no prompt
                                        offered_version > my_version?      no ─▶ ignore
                                        SKEY_OTA_ALLOWED enabled?          no ─▶ ignore
                                        battery ok (or charging)?          no ─▶ ignore (see note)
                                        ▼
                                        PROMPT: "Update available <version>. Accept?"
                                        user declines ─▶ back to normal, cooldown this offer
                                        user accepts
                                        ▼
                            ◀───────    connect (GATT client) to offerer address
read META char              ───────▶    {size, chunk_size, md5[16], signature, fw_version}
                                        ▼
                                        ENTER OTA-RECEIVE screen — LOCK OUT all scans /
                                        power cycle / other behavior (see PowerManager)
                                        esp_ota_begin(inactive_slot)
request chunks (windowed)   ◀──────▶    stream chunks; per-chunk CRC; esp_ota_write
  data notifications        ───────▶    progress bar advances 0 → 100%
                                        ▼
                                        whole-image MD5 == META.md5 ?   fail ─▶ abort, erase, unlock
                                        signature valid over image ?    fail ─▶ abort, erase, unlock
                                        esp_ota_end (framework validation)
                                        ▼
                                        PROMPT: "Update ready. Install & reboot?  [Install] [Discard]"
                                        discard ─▶ leave boot partition unchanged, unlock, resume
                                        install
                                        ▼
                                        esp_ota_set_boot_partition(inactive_slot)  ("swap partitions")
                                        esp_restart()
                                        ▼ (next boot)
                                        first successful boot ─▶ esp_ota_mark_app_valid_cancel_rollback()
                                        boot fails / panics    ─▶ bootloader auto-rolls back to old slot
```

**Battery note.** Gate acceptance on a safe level so a mid-flash brownout can't
corrupt the write. Proposed: **≥ 50% or charging**. The prompt is suppressed (or
shown greyed with a "needs charge" reason) below the threshold. Constant lives
with `PowerManager`.

---

## BLE transport

### 1. Discovery — the passive offer advert

Reuses the admin receive path. The offerer advertises **connectable**
manufacturer-data frames; the scan engine's NimBLE callback filters OTA frames
into a queue alongside admin frames, and an `OtaService::tick()` drains +
authenticates them (mirrors `AdminService`).

Advert payload is kept tiny (legacy 31-byte adv; use BLE 5 extended adv only if
needed):

| field | bytes | notes |
|---|---|---|
| company id | 2 | manufacturer-data header |
| type | 1 | `OTA_OFFER` |
| fw_version | 3 | packed major.minor.patch |
| flags | 1 | reserved (e.g. mandatory-update bit) |
| HMAC (trunc) | 8–10  | over the above, admin secret |

Everything heavy (size, MD5, signature) is fetched from GATT **after** connect,
not crammed into the advert.

Offer broadcasts for a bounded window then auto-stops, exactly like admin
commands (`BROADCAST_MS`). The operator arms it from the admin menu.

### 2. Pull — GATT service on the offerer

The receiver connects as central and drives the transfer:

| characteristic | op | payload |
|---|---|---|
| `META` | read | `{ size, chunk_size, md5[16], sig[...], fw_version }` |
| `CONTROL` | write | `START`, `REQUEST(window_start, count)`, `ABORT` |
| `DATA` | notify | `{ index, bytes[] }` chunks, streamed for the requested window |

Windowed request/notify (receiver ACKs each window before the next) gives flow
control without a round-trip per chunk. Per-chunk CRC catches corruption early;
whole-image MD5 + signature are the final gates. Negotiate 2M PHY + DLE + max
MTU + a short connection interval — two ESP32-S3s aren't subject to phone-stack
caps, so ~100+ KB/s (~30 s for 3.3 MB) is realistic.

The offerer serves chunks straight from its active partition
(`esp_partition_read`); no buffering the whole image in RAM.

---

## Version comparison

`FW_VERSION_STR` comes from the `v*` git release tag (`scripts/build_info.py` →
`build_info.h`, e.g. `v2.8.2`). For OTA, embed the same semver into the image's
`esp_app_desc_t.version` (set the project version at build) so it's:

- readable from any partition on-device (`esp_app_get_description` /
  `esp_ota_get_partition_description`), and
- packable into the offer advert.

The receiver compares offered semver against its own running
`esp_app_desc_t.version`; only **strictly newer** offers pass. (Ignore `-dirty`
/ build-metadata suffixes in the compare.) Optional `flags` bit for a
force/mandatory offer that bypasses the newer-than check but never the user
prompt.

---

## Settings

One new key, append-only per the NVS convention in `settings_keys.h` (bump
`SCHEMA_VERSION`):

| key | type | default | semantics |
|---|---|---|---|
| `SKEY_OTA_ALLOWED`  | bool | **off** | receiver participates in BLE OTA (sees offers, prompts) |

Default off: OTA is opt-in. UI toggle added in EEZ (Scanning/Power section),
wired in `settings_screen.cpp` like the other switches. Offer authenticity and
image signature are *not* user-toggleable.

---

## UI

- **Prompt 1 — offer.** Modal: offered version, current version, Accept /
  Decline. Decline arms a per-offer cooldown (like admin message dismissal) so
  the same advert doesn't re-nag every scan window.
- **OTA-receive screen.** Progress bar + spinner + version label. Shown for the
  whole connected phase; **locks out all other UI/behavior** (see below). Cancel
  button aborts the transfer.
- **Prompt 2 — install.** After download + verify: "Update ready. Install &
  reboot?" Install / Discard. Discard leaves the boot partition untouched.
- **Post-reboot.** Brief "updated to <version>" confirmation on first boot, then
  `esp_ota_mark_app_valid_cancel_rollback()`.

EEZ owns the screens/widgets; C owns dynamic labels + progress. Do not hand-edit
generated `src/UI/*`.

---

## PowerManager / scan lockout

The connected transfer must own the device — no scan windows, no duty cycle, no
deep sleep, no competing radio use. Reuse the **foxhunt lock-on** mechanism
verbatim:

- An `_ota_active` flag mirrors `_hunting`: it inhibits sleep (`_isInhibited`)
  and short-circuits the whole duty-cycle state machine in `tick()` (the same
  early-return that hunting uses).
- Entering the OTA-receive screen posts a lock-on-style command; leaving /
  finishing / aborting releases it and resumes a fresh scan window.
- The battery gate keeps the device from starting a transfer it can't finish;
  the sleep inhibit keeps it awake through the transfer.

The offerer, being in admin mode, is already broadcasting; serving GATT is
additive. Its own scanning pauses while a client is connected.

---

## Failure handling

| failure | behavior |
|---|---|
| forged / unsigned offer | dropped at HMAC check; never prompts |
| offered ≤ installed version | ignored silently |
| `SKEY_OTA_ALLOWED` off | offers ignored |
| battery too low | prompt suppressed / greyed with reason |
| connection drops mid-transfer | abort, `esp_ota_abort`, erase slot, unlock, resume scanning |
| chunk CRC mismatch | re-request window; N retries then abort |
| whole-image MD5 mismatch | abort + erase (corruption) |
| signature invalid | abort + erase (**do not install**) |
| user discards after verify | boot partition unchanged; slot left for next attempt |
| new image panics on first boot | bootloader rolls back to the previous slot (never marked valid)|

---

## Implementation phases

1. **Partitions + plumbing.** Swap to the A/B table; add `OtaService` skeleton
   (`begin`/`tick`/`onEvent`); confirm `esp_ota_*` works with a serial-delivered
   image before any BLE.
2. **Secure boot decision + signing.** Decide Secure Boot v2; wire image signing
   into the build; implement receiver-side signature verify.
3. **Discovery.** Offer advert (offerer) + scan-engine filter + authenticate +
   version/policy/battery gate + Prompt 1 (receiver).
4. **Transport.** GATT server (offerer, serves active partition) + client pull
   (receiver) + windowed chunk protocol + CRC.
5. **Receive + verify + install.** OTA-receive screen, progress, MD5 +
   signature gates, Prompt 2, `set_boot_partition` + reboot + rollback-arm.
6. **Lockout + power.** `_ota_active` inhibit (mirror foxhunt), battery gate
   constant, `SKEY_OTA_ALLOWED` + UI toggle.

---

## Open questions

- **Secure Boot v2**: enable before first signed release? (Recommended; one-way,
  can't retrofit fielded units.)
- **Battery threshold**: 50%? charging-only? charging-OR-≥X%?
- **MD5 vs SHA-256** for the integrity field — MD5 per the flow, but SHA-256 is
  already used by `esp_partition_get_sha256`; consider reusing it and dropping
  MD5 entirely.
- **Legacy vs extended advertising** for the offer frame — start legacy (31 B)
  with meta-over-GATT; only move to BLE 5 ext-adv if the advert must self-carry
  more.
- **Mandatory updates**: honor a force flag (bypass newer-than) for security
  fixes, or always require strictly-newer?

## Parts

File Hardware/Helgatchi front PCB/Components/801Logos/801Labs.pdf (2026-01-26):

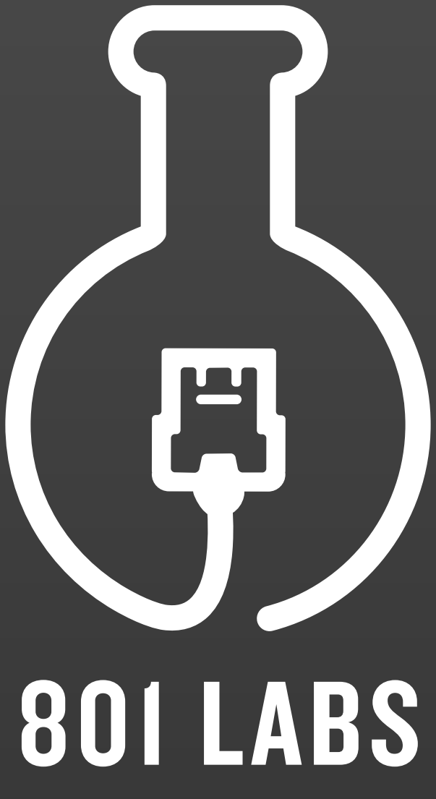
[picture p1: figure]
801 LABS

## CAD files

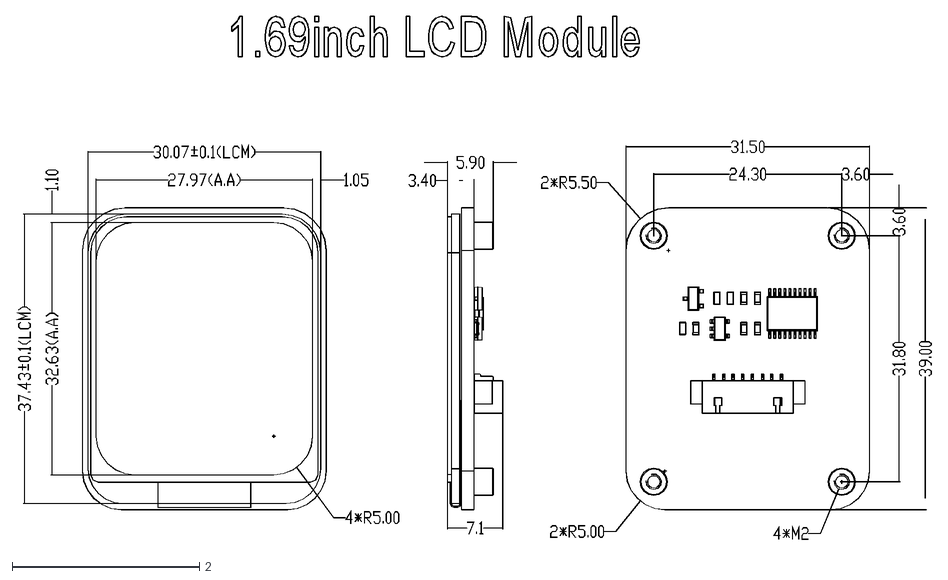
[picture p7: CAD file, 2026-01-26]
Hardware/Helgatchi front PCB/Components/1.69 inch LCD/1.69inch_LCD_Module_2Ddrawing.dxf
9.76 x 5.58

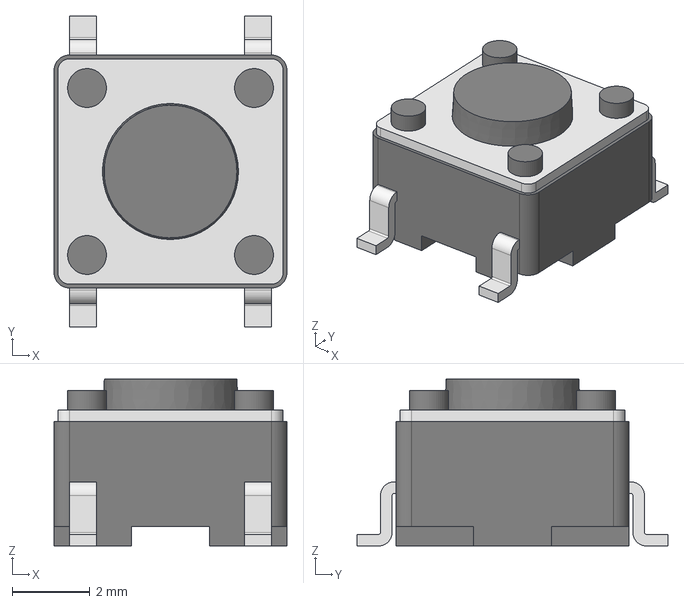
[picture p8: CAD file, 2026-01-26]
Hardware/Helgatchi front PCB/Components/Adafruit everse-mount SMD Button/button_smd_6x6x4.3.stp
6.00 x 8.00 x 4.30 mm

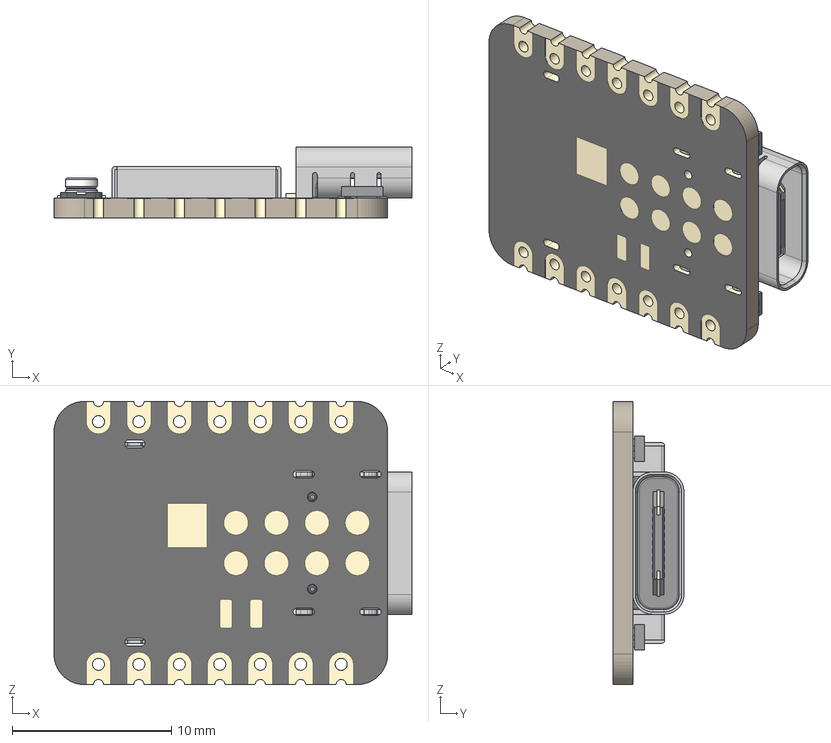
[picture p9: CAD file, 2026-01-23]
Hardware/Helgatchi front PCB/Components/Seeed Studio XIAO Series/XIAO-ESP32S3 v2.step
22.5 x 4.46 x 17.8 mm
BOSS-EXTRUDE14_8_
BOSS-EXTRUDE7_4_
BOSS-EXTRUDE7_3_
BOSS-EXTRUDE14_4_
BOSS-EXTRUDE14_2_
BOSS-EXTRUDE14_11_
BOSS-EXTRUDE7_7_
BOSS-EXTRUDE14_9_
BOSS-EXTRUDE14_3_
BOSS-EXTRUDE14_7_
MIRROR2
BOSS-EXTRUDE14_5_
BOSS-EXTRUDE14_12_
BOSS-EXTRUDE7_8_
BOSS-EXTRUDE7_1_
BOSS-EXTRUDE14_10_
BOSS-EXTRUDE7_9_
BOSS-EXTRUDE14_6_
BOSS-EXTRUDE14_1_
BOSS-EXTRUDE7_6_
BOSS-EXTRUDE7_2_
CUT-EXTRUDE5
BOSS-EXTRUDE7_5_
Shield
Pins x 2
U.FL-R-SMT-1_10_ v1

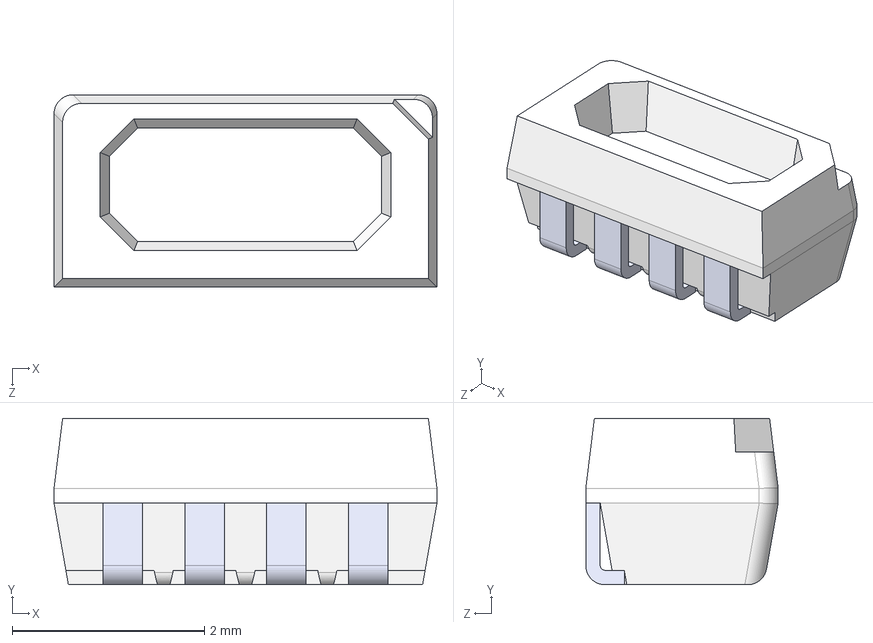
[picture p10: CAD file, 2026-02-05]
Hardware/Helgatchi front PCB/Components/WS2812/WS2812B-4020.STEP
3.98 x 1.73 x 2.00 mm

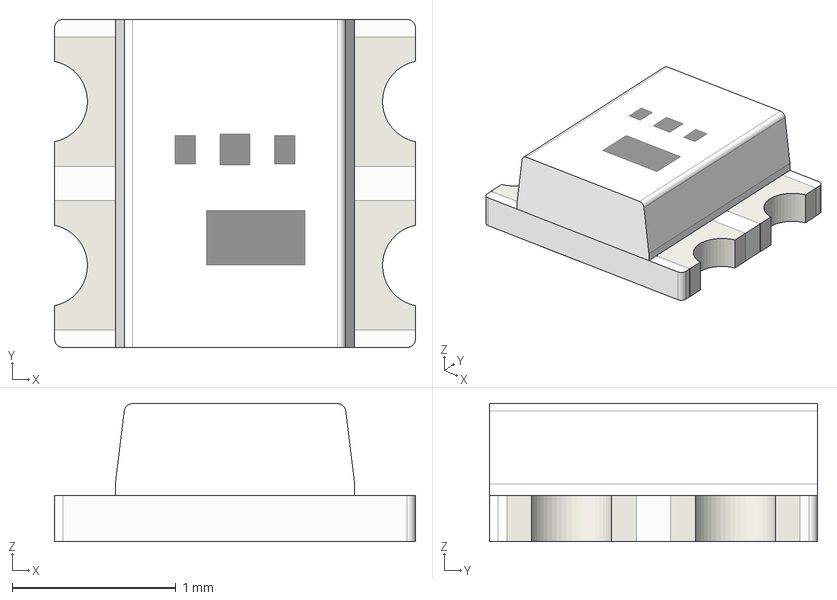
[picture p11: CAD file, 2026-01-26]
Hardware/Helgatchi front PCB/Components/WS2812B 2020/LED_WS2812_2020.step
2.20 x 2.00 x 0.842 mm

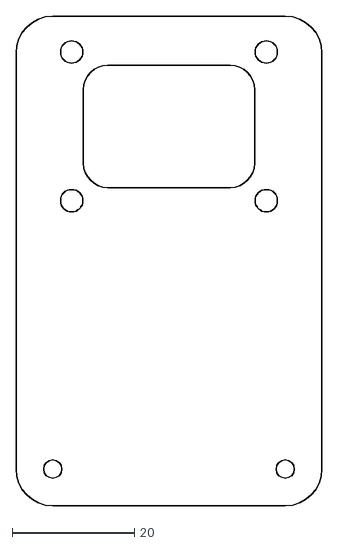
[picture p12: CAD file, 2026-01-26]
Hardware/Helgatchi front PCB/Helgatchi front PCB-Edge_Cuts.dxf
50.0 x 80.0

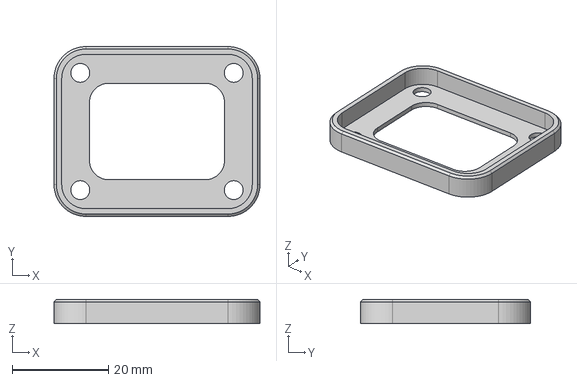
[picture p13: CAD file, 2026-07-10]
Hardware/Helgatchi Spacer/screen bumper.step
42.7 x 35.2 x 5.00 mm

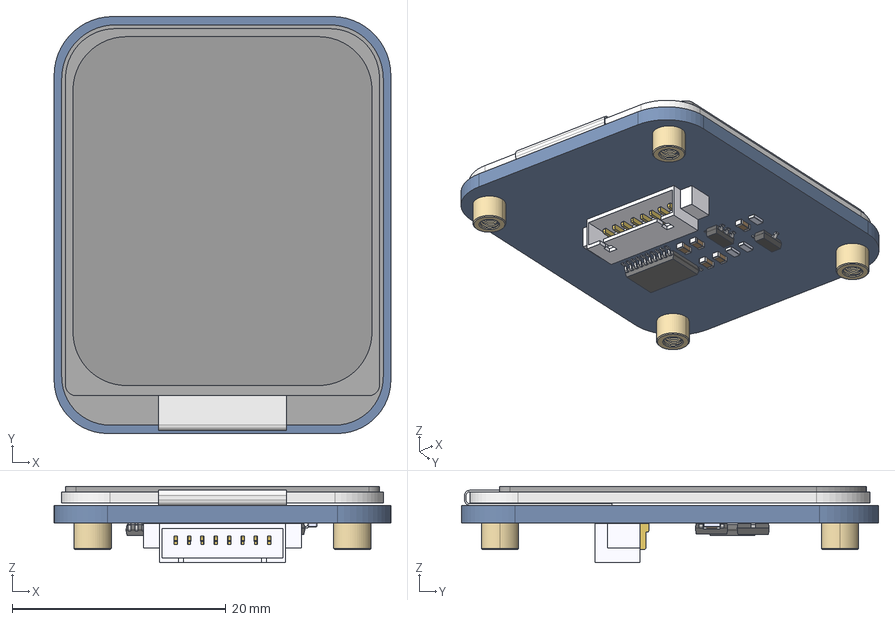
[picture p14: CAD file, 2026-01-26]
Hardware/Helgatchi front PCB/Components/1.69 inch LCD/1_69inch-lcd-module.stp
31.5 x 39.0 x 7.11 mm
1_69INCH-240X280-LCD
1_69INCH_LCD_MODULE-PCBA
STUDS-M2XH2_5 x 4

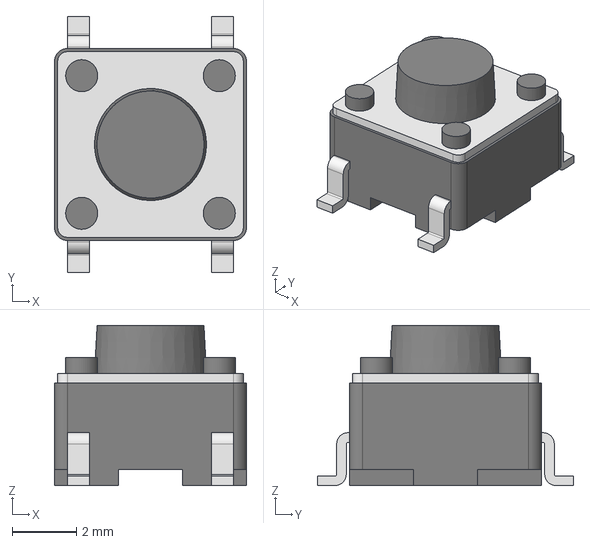
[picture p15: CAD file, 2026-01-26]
Hardware/Helgatchi front PCB/Components/Adafruit everse-mount SMD Button/button_smd_6x6x5.0.stp
6.00 x 8.00 x 5.00 mm

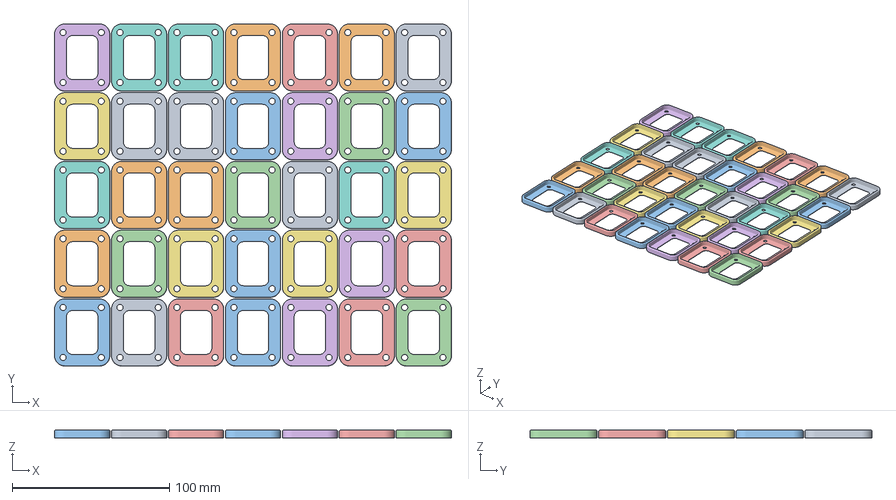
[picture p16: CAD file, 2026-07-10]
Hardware/Helgatchi Spacer/screen bumper stacked.3mf
252.6 x 217.7 x 5.00 mm
screen bumper.step
screen bumper.step 1
screen bumper.step 2
screen bumper.step 3
screen bumper.step 4
screen bumper.step 5
screen bumper.step 6
screen bumper.step 7
screen bumper.step 8
screen bumper.step 9
screen bumper.step 10
screen bumper.step 11
screen bumper.step 12
screen bumper.step 13
screen bumper.step 14
screen bumper.step 15
screen bumper.step 16
screen bumper.step 17
screen bumper.step 18
screen bumper.step 19
screen bumper.step 20
screen bumper.step 21
screen bumper.step 22
screen bumper.step 23
screen bumper.step 24
screen bumper.step 25
screen bumper.step 26
screen bumper.step 27
screen bumper.step 28
screen bumper.step 29
screen bumper.step 30
screen bumper.step 31
screen bumper.step 32
screen bumper.step 33
screen bumper.step 34

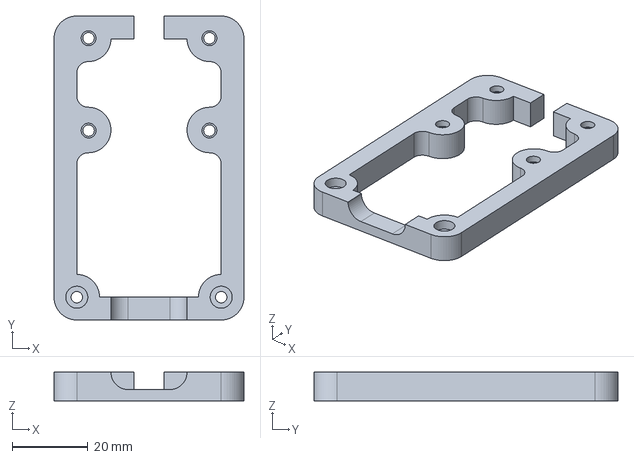
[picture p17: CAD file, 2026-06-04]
Hardware/Helgatchi Spacer/Spacer.FCStd
50.0 x 80.0 x 7.60 mm

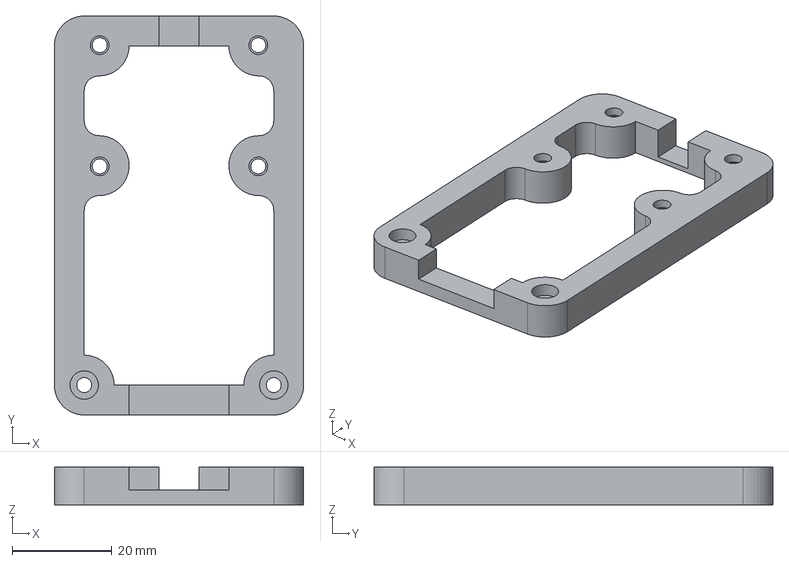
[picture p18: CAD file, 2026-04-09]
Hardware/Helgatchi Spacer/Conjoined Spacer.step
50.0 x 80.0 x 7.60 mm

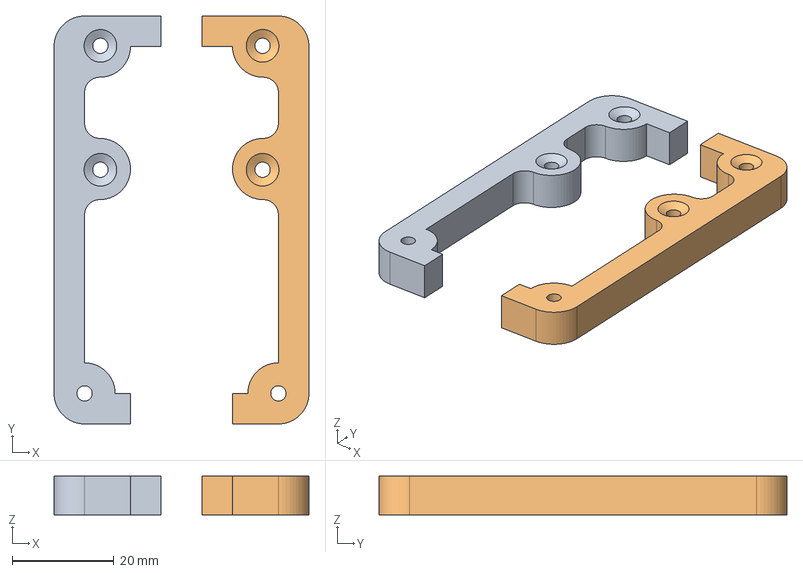
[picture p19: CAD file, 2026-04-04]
Hardware/Helgatchi Spacer/7.6mm Spacer antenna cutout 3mm holes.step
50.0 x 80.0 x 7.60 mm

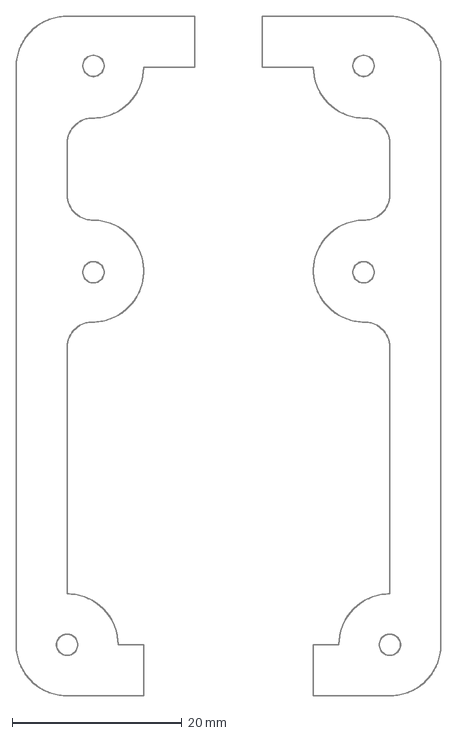
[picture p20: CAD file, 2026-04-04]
Hardware/Helgatchi Spacer/Helgatchi back PCB.dxf
50.0 x 80.0 mm

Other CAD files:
Hardware/Helgatchi Spacer/Spacer-Body.step
Hardware/Helgatchi Spacer/Helgatchi back PCB-User_Drawings.FCStd
Hardware/Helgatchi Spacer/8.6mm Spacer antenna cutout 2.5mm holes.step
Hardware/Helgatchi Spacer/8.6mm Spacer antenna cutout 3mm holes.step
Hardware/Helgatchi Spacer/7.6mm Spacer antenna cutout 2.5mm holes.step
Hardware/Helgatchi Spacer/7.6mm Spacer.step
Hardware/Helgatchi Spacer/8.6mm Spacer.step
Hardware/Helgatchi Spacer/Conjoined Spacer.3mf
Hardware/Helgatchi Spacer/Helgatchi Spacer - antenna - 2.5mm holes.dxf
Hardware/Helgatchi Spacer/Helgatchi Spacer - antenna - standoffs.dxf
Hardware/Helgatchi Spacer/Helgatchi Spacer.dxf
Hardware/Helgatchi Spacer/Helgatchi back PCB-User_Drawings - unknown variant.dxf
Hardware/Helgatchi Spacer/Helgatchi back PCB-User_Drawings.dxf
Hardware/Helgatchi Spacer/Helgatchi spacer - antenna - 2.2mm holes.dxf

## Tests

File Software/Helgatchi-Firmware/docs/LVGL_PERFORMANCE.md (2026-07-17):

# LVGL / LovyanGFX Performance on ESP32-S3

How the Helgatchi UI went from 1-3 FPS to 20+ FPS on the heaviest screen, and
40-50 FPS on menus — on the same hardware, with the same visual design.

Every technique here is transferable. The stack: ESP32-S3 (240 MHz, 8 MB
QSPI/OPI PSRAM), ST7789 280×240 over 80 MHz SPI, LVGL 9.5 software renderer,
LovyanGFX panel driver, Arduino framework under PlatformIO. The defaults of
this stack are **capacity-minded, not performance-minded**: they favor "fits
in any RAM budget" (PSRAM everything) and "smallest binary" (`-Os`) over frame
rate. Almost everything below is undoing one of those defaults deliberately.

Measured journey on the devices screen (a scrollable list of 140+ cards):

| Change round | Scroll FPS |
| --- | --- |
| Baseline (all defaults) | 1-3 |
| Memory placement + `-O2` + style cache | ~5 |
| Recycler (constant widget count) | ~15 |
| Buffer-size fix + zero-copy swapped DMA | 15-20 |
| Radius 0 + label merge + scroll-anim cap | 20+ |

Menus (light screens) went from 20-30 to 40-50 FPS from the global changes
alone — they had the same memory-placement tax, just fewer objects paying it.

---

## 0. Measure before touching anything

Nothing below was guessed; each round targeted the number that was actually
biggest. The instrumentation that made that possible:

- **LVGL's perf monitor** (`LV_USE_SYSMON` + `LV_USE_PERF_MONITOR`) for FPS
  and CPU%, gated behind a debug setting so it ships disabled.
- **Render vs flush split**: wall-time inside the flush callback is
  accumulated separately (`_flush_us_total` in `ui_controller.cpp`), and
  `tick()` diffs it per frame. "Render 240 ms, flush 11 ms" pointed at
  rasterization; the reverse would have pointed at the SPI link.
- **Loop-phase telemetry**: microseconds per service per loop iteration
  (scan, rules, UI, …) over teleplot. This ruled out the alternative
  hypothesis that the UI was being *starved* by the scan engine rather than
  being slow itself.

Two diagnostic questions did most of the aiming:

1. **Does FPS degrade with total content, or only visible content?** Visible
   content is constant on a list screen (~6 cards fit), so "more devices =
   slower" meant the cost was structural (per-object overhead), not pixel
   work. That conclusion is what justified the recycler.
2. **Does FPS recover when idle?** Idle-recovers means the cost is the redraw
   itself; idle-also-bad means something is invalidating continuously (timers,
   data refreshes) and you have a different bug.

---

## 1. Memory placement is the whole game on ESP32-S3

The single biggest lesson. The S3's PSRAM sits behind a QSPI/OPI bus at
80 MHz with a small data cache in front. Anything the renderer touches per
pixel or per object **must not live there**.

### Draw buffers → internal SRAM, DMA-capable

The software renderer *read-modify-writes* the strip buffer for every blend:
anti-aliased glyph edges, rounded corners, borders, any opacity. A render
strip larger than the data cache degrades every one of those accesses to
PSRAM bus speed. This alone was the difference between ~1 FPS and ~15 FPS.

```cpp
buf = heap_caps_malloc(BYTES, MALLOC_CAP_DMA | MALLOC_CAP_INTERNAL);
```

Partial-render strips keep the footprint sane: 3 strips of 80 rows
(2 × 44.8 KB) instead of a full framebuffer. Fewer, larger strips = fewer
tree walks per frame and fewer tear seams; the limit is internal heap.

### The `lv_color_t` sizing trap (LVGL 9)

In LVGL 9, `lv_color_t` is **always a 3-byte RGB888 struct**, regardless of
`LV_COLOR_DEPTH`. Sizing RGB565 buffers with `sizeof(lv_color_t)` silently
over-allocates them by 50% — LVGL just quietly makes taller strips out of the
extra bytes, so nothing visibly breaks and the RAM is gone. Use
`lv_color16_t` (or an explicit `* 2`).

### The LVGL heap can stay in PSRAM — with a mitigation

512 KB of widget pool doesn't fit in internal SRAM, and unlike the draw
buffer, object memory is touched hundreds of times per frame rather than
millions. It stays in PSRAM (`LV_MEM_POOL_ALLOC` → `heap_caps_malloc(...,
MALLOC_CAP_SPIRAM)`), and two things blunt the cost:

- `LV_OBJ_STYLE_CACHE 1` — 8 bytes per object to skip most style-list
  walks, which are pure pointer-chasing through PSRAM during draw.
- Keeping the object *count* small (§3), so the walk that does happen is
  short.

### Know that IRAM and heap are the same pool

`LV_ATTRIBUTE_FAST_MEM = IRAM_ATTR` looks tempting (hot render loops out of
flash cache), but on the S3 instruction RAM and data RAM come out of the same
512 KB SRAM. It converts scarce heap into a modest icache win. Rejected here;
only worth it if you have RAM to burn.

---

## 2. The flush path: overlap everything, copy nothing

### Double-buffer + deferred `endWrite`

Two equal strips let LVGL rasterize strip N+1 while strip N is on the DMA
bus. The flush callback intentionally does **not** wait for the transfer: it
starts the DMA, calls `lv_display_flush_ready()` immediately, and the *next*
flush drains the previous transfer before reusing the bus. The SPI link runs
essentially 100% duty during a frame.

### If you DMA from PSRAM, write back the cache

The CPU writes pixels through the data cache; GDMA reads physical PSRAM.
Without `Cache_WriteBack_Addr()` (rounded out to 32-byte lines) before each
transfer, the DMA reads stale bytes — the classic green-glitch corruption.
Internal SRAM is DMA-coherent; this cost disappears when buffers move there
(keep it on the fallback path only).

### Render in the panel's byte order — zero-copy DMA

RGB565 panels want MSB-first; LVGL renders CPU-native little-endian by
default. LovyanGFX's `writePixelsDMA(..., swap=true)` fixes that by routing
every strip through a **CPU swap-copy into its own DMA buffer**. The better
fix is to make the swap never happen:

```cpp
lv_display_set_color_format(disp, LV_COLOR_FORMAT_RGB565_SWAPPED);  // LVGL side
tft.writePixelsDMA((uint16_t*)px_map, px_count, /*swap=*/false);    // flush side
```

LVGL 9's SW renderer supports `RGB565_SWAPPED` natively (including image and
font blending — sprites, indexed images, and QR canvases all verified fine).
These two lines must flip together or every color mashes.

### Know your wire ceiling

280×240×16 bit at 80 MHz SPI ≈ 13.4 ms per full-screen push ≈ 74 FPS
absolute ceiling for full redraws. Worth computing early — it tells you when
flush will become the next bottleneck and whether panel-link upgrades matter.

### FULL render mode: tried, reverted

One flush per frame reduced tear seams from 2 to 1 but the seam was still
visible during scrolls, and small isolated updates paid a full-screen cost.
PARTIAL with pipelined strips won.

---

## 3. LVGL cost scales with objects that *exist*, not objects you *see*

The most counter-intuitive lesson, and the biggest single win.

Off-screen widgets are clipped before drawing, but they are **not free**:
every refresh walks the tree per strip (coordinate reads, clip tests, cover
checks), every scroll step updates coordinates on every child recursively,
and every invalidation clips against the whole child list. With objects in
PSRAM, each touch is a cache miss. A 140-card list (≈900 objects) cost
~240 ms/frame while drawing only 6 cards.

### The recycler (fixed pool + spacers)

Replace one-widget-per-row with:

```
[ top spacer ][ card 0..11 (pool) ][ bottom spacer ]
```

- **Data lives in a plain C array** (the "rows"): rebuild + re-sort on data
  events costs microseconds and zero LVGL work.
- **The pool binds to a sliding window** around the selection; binding is
  just label-text writes, off the per-frame path entirely.
- **Spacers stand in for off-window rows**, sized `rows_outside × pitch −
  pad_row` (the correction returns the flex gap the spacer itself inserts).
  This makes every row's Y and the total content height **pixel-identical to
  a real full list** — scroll range, scrollbar, and snap behave as if all
  rows existed. This is what a naive push/pop virtualization gets wrong: the
  content height keeps changing and the scroll position "snaps around".
- Derive the pitch from live styles (widget height + container `pad_row`) at
  pool-build time so a designer-side tweak can't desync the math.
- **Selection becomes a data index**, not an LVGL focus object — widgets are
  reused, so "the focused widget" no longer identifies a row. Pin the
  selection by stable identity (here: domain+MAC) so re-sorts follow the
  item. The bound card just gets `LV_STATE_FOCUS_KEY` so existing styles
  render unchanged.

Bonus: deleting per-row widget creation also deletes the entire class of
"widget pool exhausted mid-build" failure modes and their workaround code.

---

## 4. Do less work: guard, defer, throttle

A batch of small patterns that each remove invisible-but-real work:

- **`set_text` is never free.** Even with identical text it reallocs,
  re-measures, and invalidates. Guard every programmatic label write:
  ```cpp
  if (strcmp(lv_label_get_text(lbl), s) != 0) lv_label_set_text(lbl, s);
  ```
  Same for `lv_label_set_long_mode` — no same-value early-out; an unguarded
  call kills and restarts the scroll animation every time.
- **Defer data refreshes while a scroll animation runs**
  (`lv_anim_get(container, NULL)` + a short retry timer). A rebind
  mid-glide fights the animation for frame time and yanks the viewport.
- **Throttle live-updating labels, and only touch what's on screen.** The
  "Ns ago" tick went from every-second-every-card to every-5s-bound-cards.
  Data freshness policy belongs to the data event (RSSI updates only when a
  scan lands), not to a UI timer.
- **Expensive per-item animations only on the selected item.**
  `SCROLL_CIRCULAR` marquee is a continuous invalidation; run it on the one
  selected card, `DOTS` everywhere else. LVGL only starts the marquee when
  text actually overflows, so it's free when not needed.
- `lv_obj_move_to_index` no-ops when the index is unchanged, but real moves
  dirty the parent's flex layout — avoid reorder churn on jittery sort keys.

---

## 5. Cheap render wins that don't change the design

- **`-O2` instead of Arduino's default `-Os`** (`build_unflags = -Os`). The
  blend/blit inner loops are exactly the code size-optimization hurts. Bonus:
  changing build flags forces a full rebuild, which also flushes PlatformIO's
  stale-library-archive footgun for `lv_conf.h` changes.
- **Corner radius 0 on opaque list items.** Not about corner-mask cost: a
  fully opaque *rectangular* widget passes LVGL's cover check, so the parent
  background underneath is never painted. Rounded corners force the parent to
  be drawn and then covered — full overdraw per item, every frame.
- **Merge labels that share a font.** `LV_SYMBOL_*` icons are ordinary glyphs
  in the Montserrat fonts — an icon label + name label at the same size is
  strictly worse than one label with the symbol inline. Each merged label is
  one fewer object in every tree walk and one fewer draw task. (Inline font
  *size* changes are impossible in a label — font is a per-part style;
  recolor `#RRGGBB #` is color-only. Mixed sizes need `lv_spangroup`.)
- **Cap scroll-glide duration.** LVGL scrolls at 120 px/s clamped to
  `[SCROLL_ANIM_TIME_MIN, SCROLL_ANIM_TIME_MAX]` ms (200/400 defaults,
  `#ifndef`-guarded → override via `-D` build flags). Every animated frame is
  a full redraw of the moved area, so a 400 ms glide at 20 FPS is ~8 redraws
  per keypress. 300 ms tested as the feel/cost compromise here. These defines
  are global; a per-page custom `lv_anim` glide was tried and reverted — it
  saved nothing (same per-frame scroll work) and felt worse.
- Disable per-label features you don't use (`LV_LABEL_TEXT_SELECTION 0` on a
  touchless device).

---

## 6. Tried and rejected (so nobody re-treads)

| Idea | Verdict |
| ---- | --- |
| FULL render mode for tear-free scrolls | 1 seam remained, small updates got slower — reverted |
| Per-page scroll animation via custom `lv_anim` | Same per-frame cost as stock; global clamp is simpler — reverted |
| `LV_ATTRIBUTE_FAST_MEM = IRAM_ATTR` | IRAM and heap share the S3's SRAM; trades scarce heap for a small icache win |
| Hidden-flag / push-pop list virtualization | Flex height changes as items appear → scroll position snaps; spacer-recycler solves it |
| Moving the 512 KB LVGL pool to internal SRAM | Doesn't fit; style cache + low object count is the practical substitute |
| Runtime CPU frequency scaling (earlier session) | `setCpuFrequencyMhz` hangs this board (MSPI/flash+PSRAM timing) — dead idea, see `docs/CPU_SCALING.md` |
| Capping the device list to top-N | Product call: the list must show everything |

---

## 7. Remaining headroom (if ever needed)

- Fewer/simpler labels per card (2-line composition instead of 4 labels).
- `LV_ANIM_OFF` selection stepping — one redraw per keypress, zero glide
  cost; a feel tradeoff, not a technical one.
- Scrollbar off (deliberately kept: it communicates list length).
- Espressif's Xtensa SIMD (PIE) blend routines via `LV_USE_DRAW_SW_ASM` —
  real gains, painful integration under Arduino/PlatformIO.
- SPI link is good to ~74 FPS full-frame; not the bottleneck yet.

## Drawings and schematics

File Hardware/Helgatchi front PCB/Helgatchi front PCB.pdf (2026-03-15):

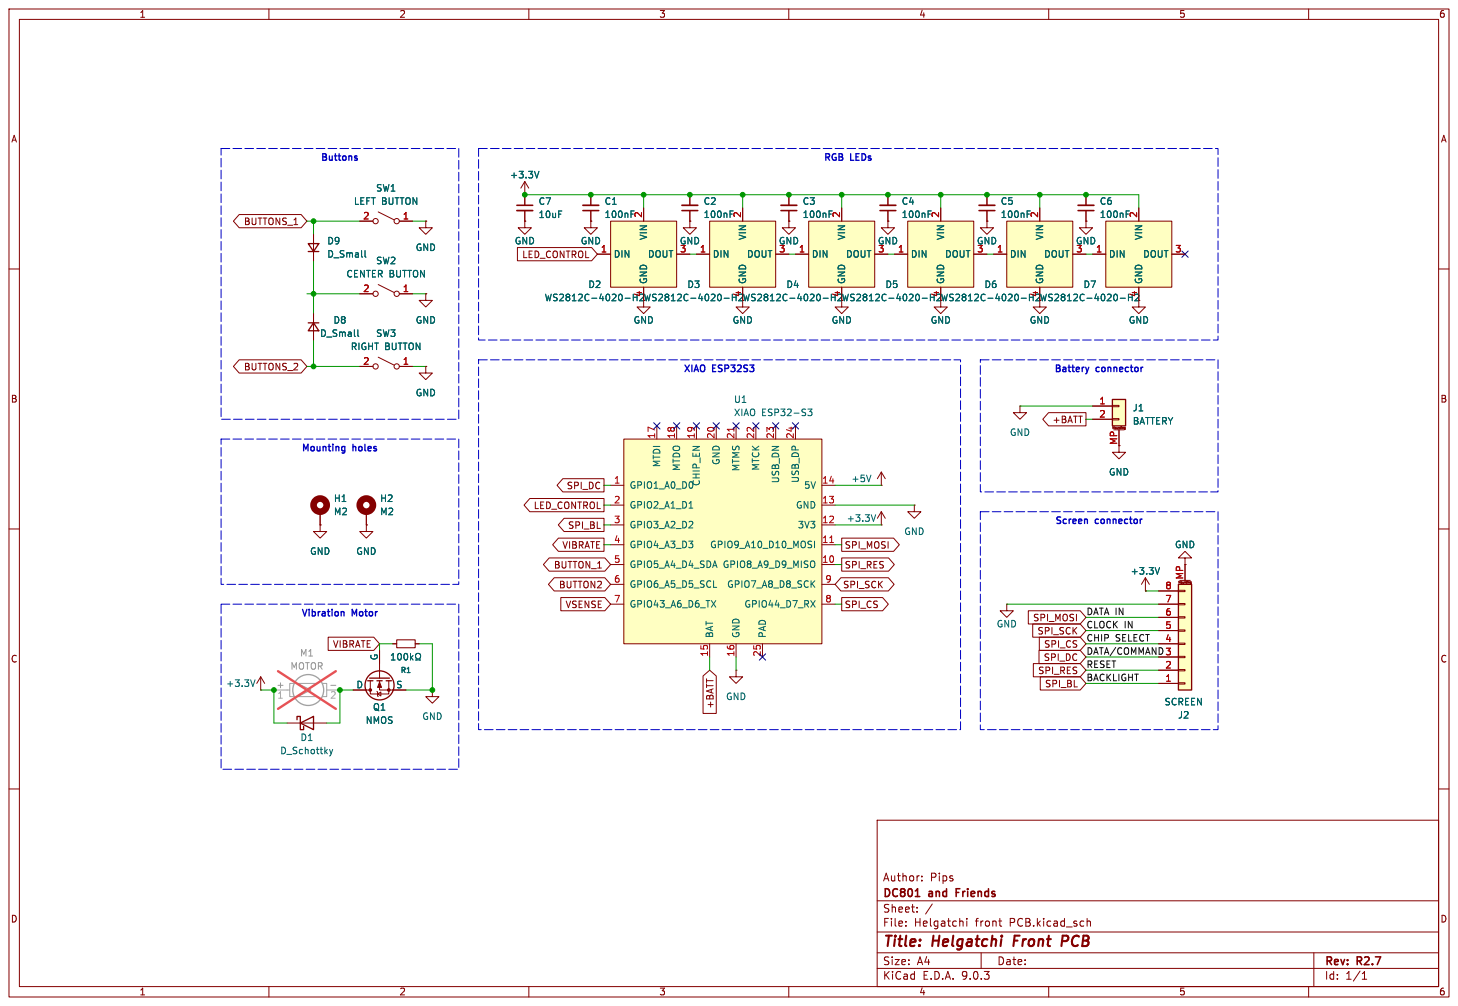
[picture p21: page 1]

4 DOUT 3 D3 WS2812C-4020-H2 GND GND GND

4 DOUT 3 D7 WS2812C-4020-H2 GND GND GND

CHIP SELECT BACKLIGHT DATA/COMMAND

Id: 1/1 Title: Helgatchi Front PCB

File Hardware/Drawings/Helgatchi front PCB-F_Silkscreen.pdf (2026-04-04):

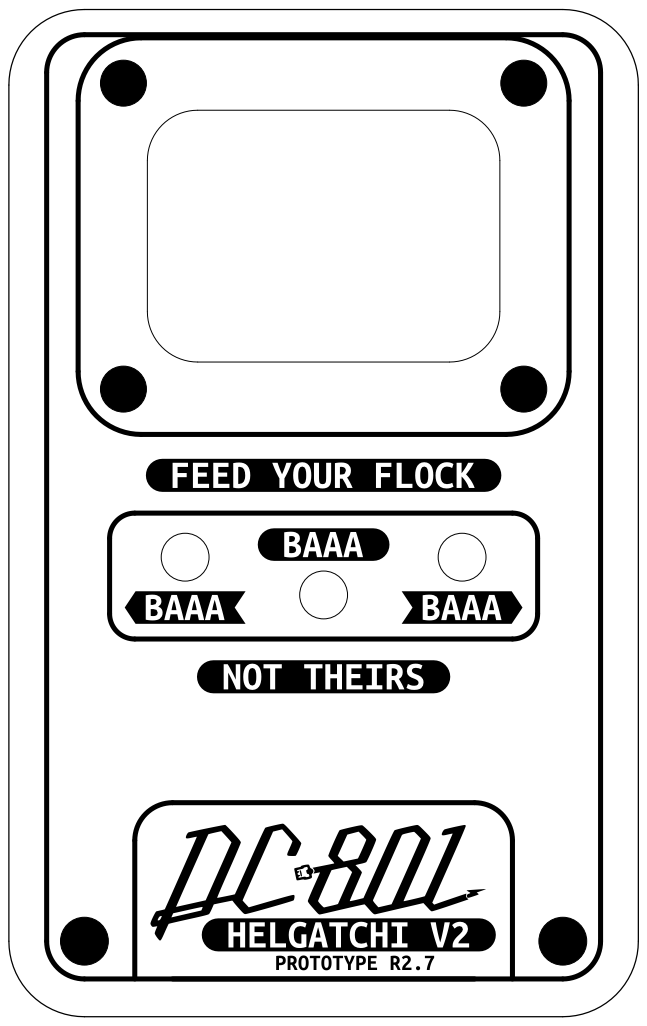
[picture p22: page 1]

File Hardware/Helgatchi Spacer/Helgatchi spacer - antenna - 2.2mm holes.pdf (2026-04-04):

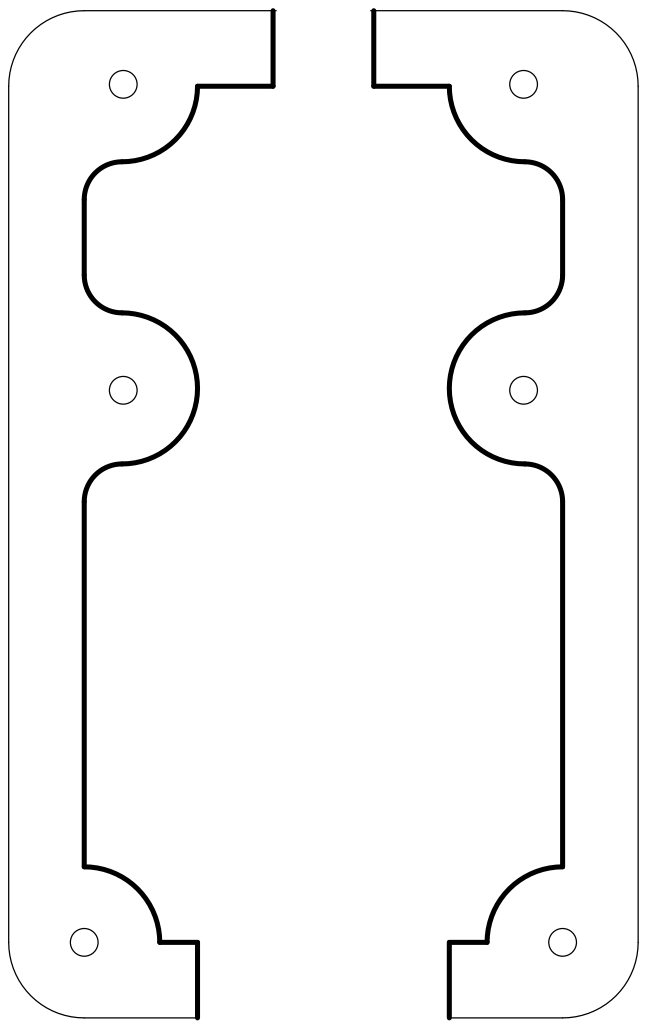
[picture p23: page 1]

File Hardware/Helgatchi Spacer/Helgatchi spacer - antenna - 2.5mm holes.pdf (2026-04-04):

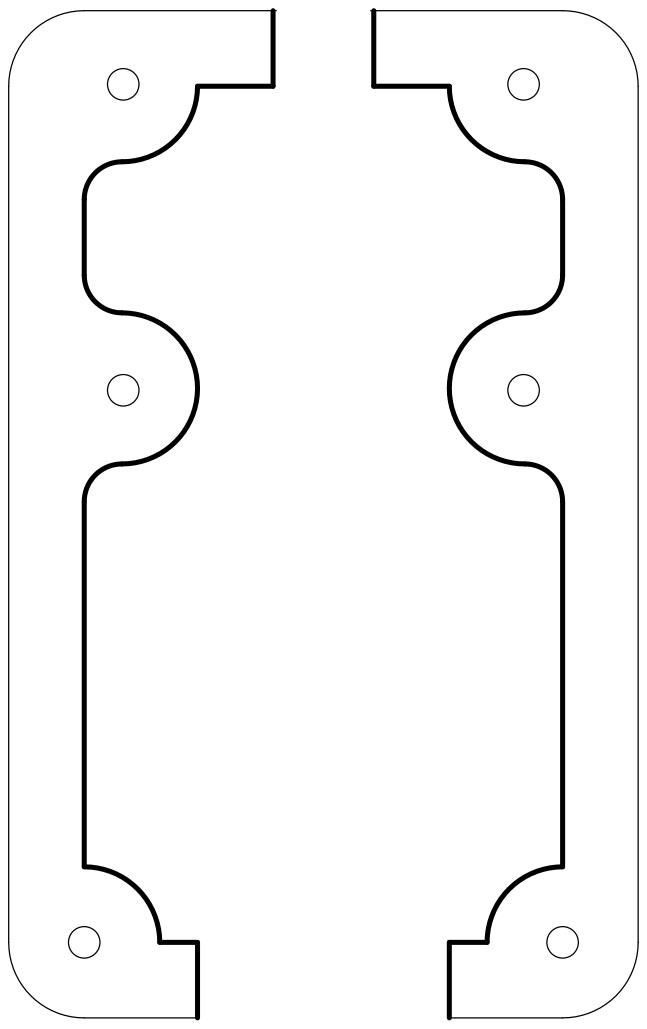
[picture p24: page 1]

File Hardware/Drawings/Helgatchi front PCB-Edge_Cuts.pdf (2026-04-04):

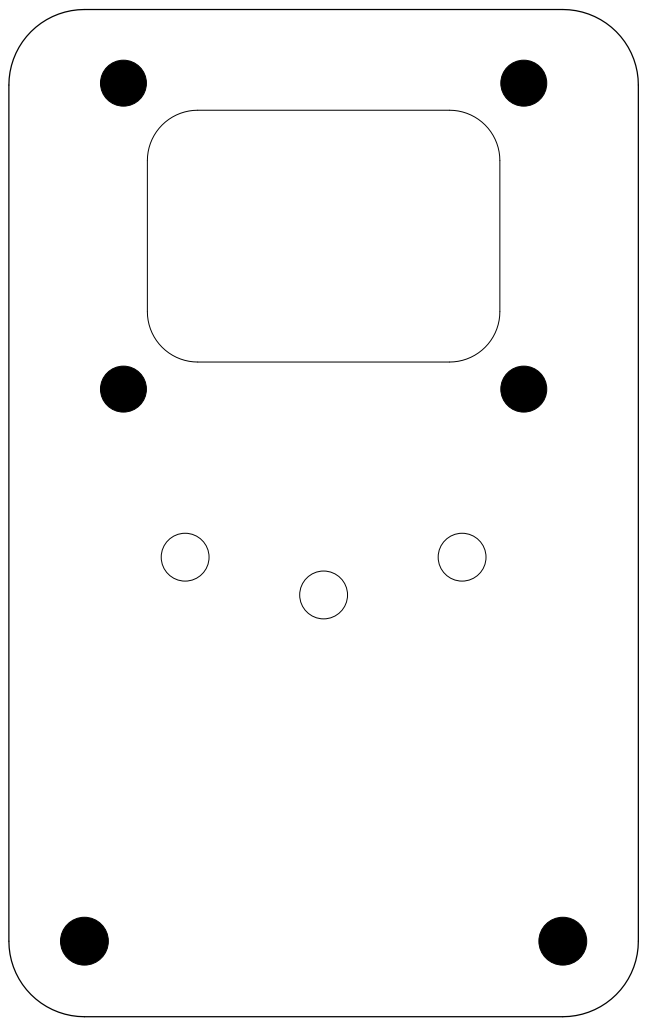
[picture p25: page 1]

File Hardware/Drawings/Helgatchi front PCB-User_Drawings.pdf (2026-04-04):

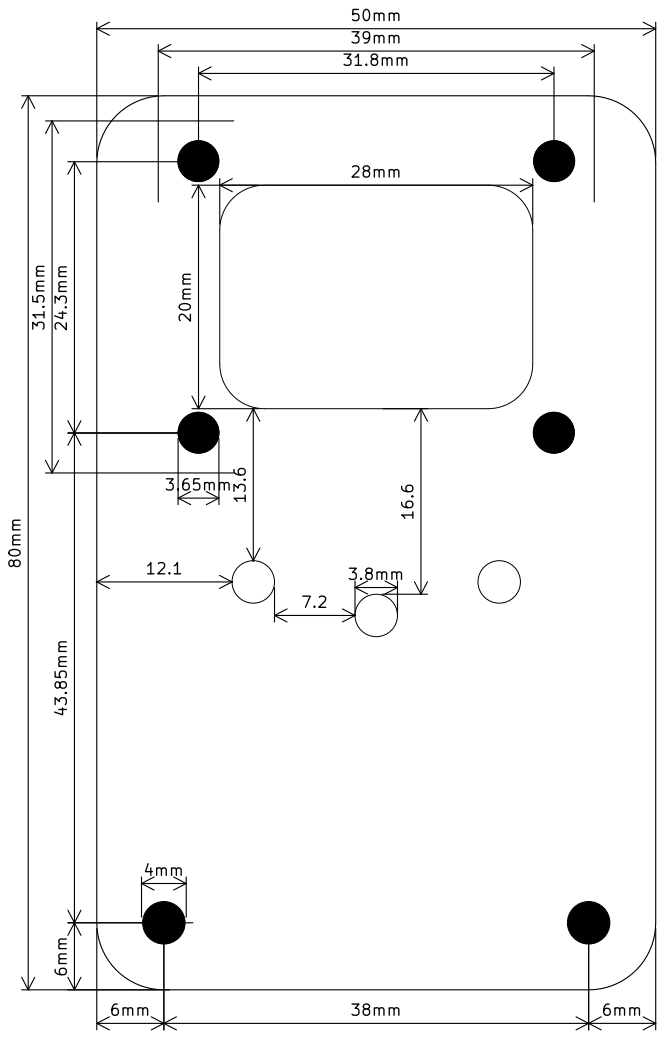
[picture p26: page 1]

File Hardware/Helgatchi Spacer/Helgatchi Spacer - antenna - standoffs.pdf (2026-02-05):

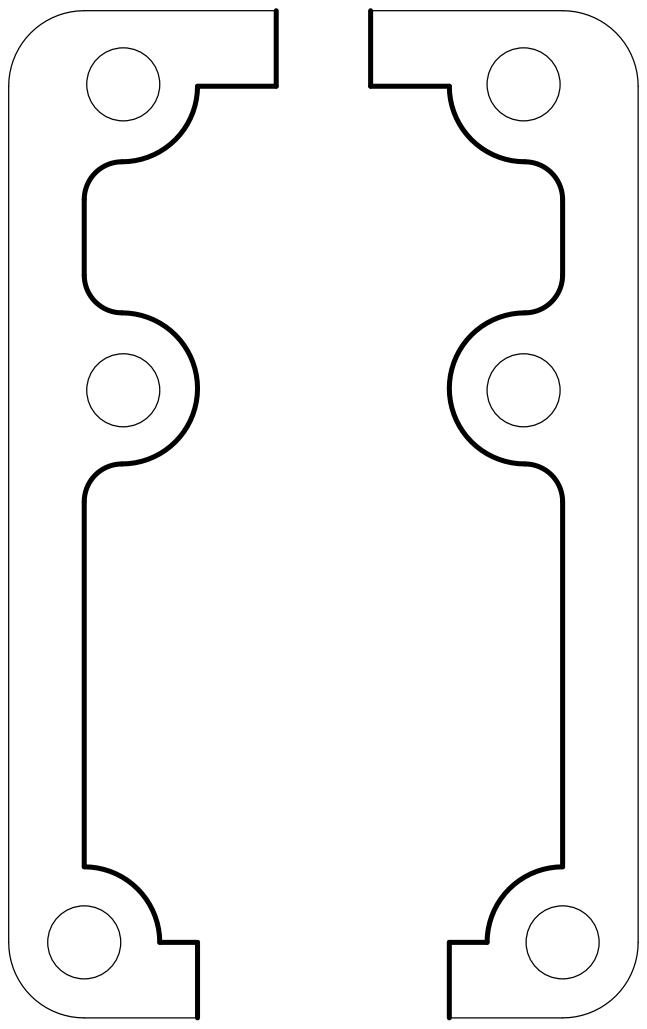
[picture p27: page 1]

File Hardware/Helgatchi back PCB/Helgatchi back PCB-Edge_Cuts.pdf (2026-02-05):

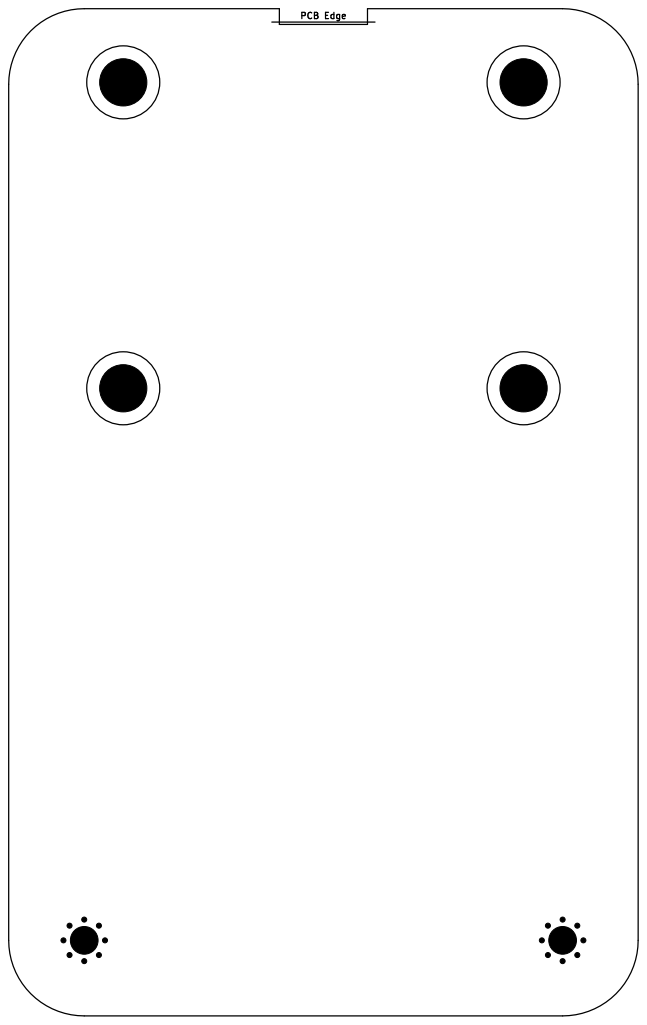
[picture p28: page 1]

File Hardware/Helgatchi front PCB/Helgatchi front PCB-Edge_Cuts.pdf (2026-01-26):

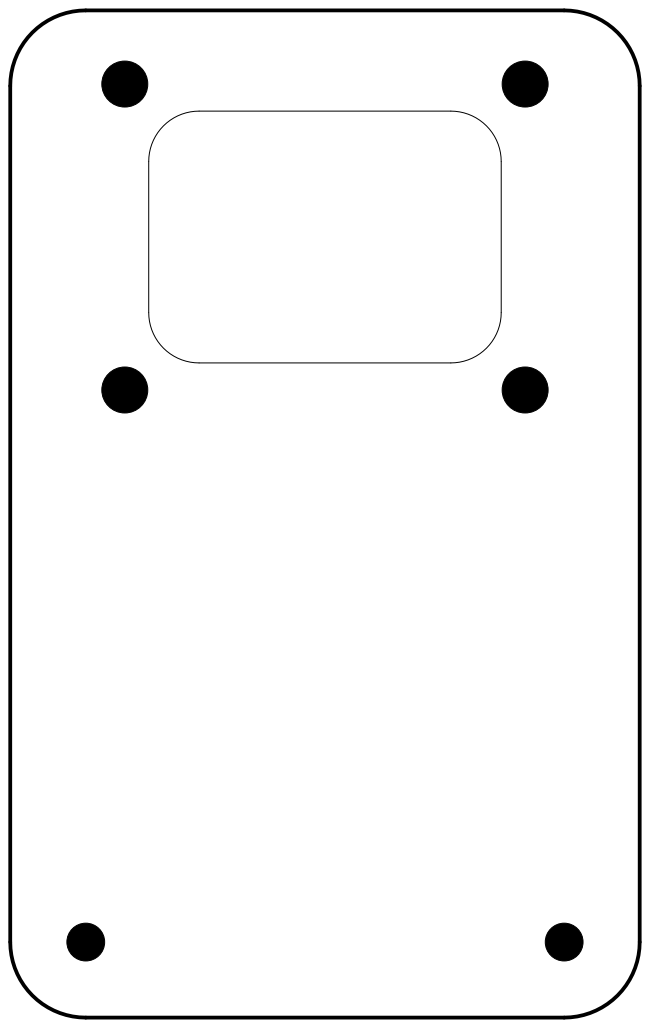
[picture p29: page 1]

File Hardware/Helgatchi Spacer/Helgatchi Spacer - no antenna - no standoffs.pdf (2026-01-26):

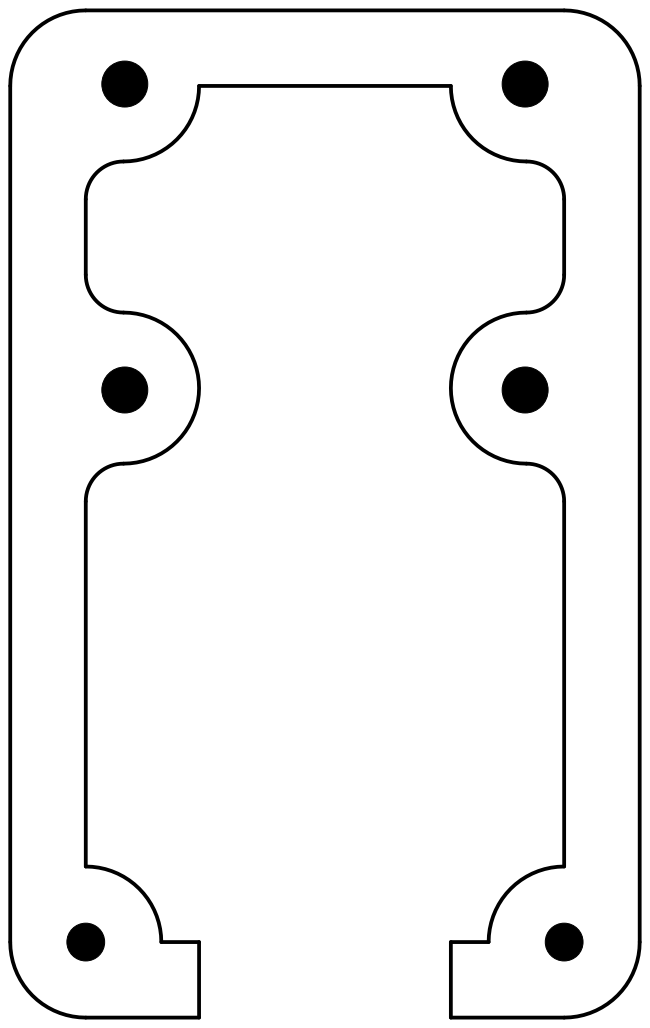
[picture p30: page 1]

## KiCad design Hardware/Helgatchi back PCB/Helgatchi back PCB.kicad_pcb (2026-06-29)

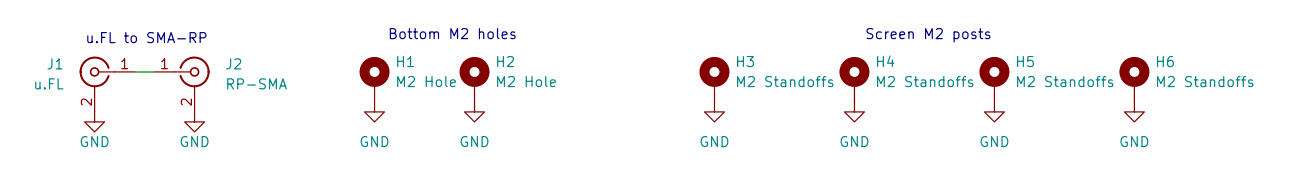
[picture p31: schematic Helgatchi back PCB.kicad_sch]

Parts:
H1, H2: M2 Hole; MountingHole_2.2mm_M2_Pad_Via
H3, H4, H5, H6: M2 Standoffs; MountingHole_2.2mm_M2_Pad_Via; LCSC Part # C2928171
J1: u.FL; U.FL_Molex_MCRF_73412-0110_Vertical; LCSC Part # C411563
J2: RP-SMA; SMA_Amphenol_901-143_Horizontal; LCSC Part # C1509217

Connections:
GND: H1.1, H2.1, H3.1, H4.1, H5.1, H6.1, J1.2 (Ext), J2.2 (Ext)
unnamed: J1.1 (In), J2.1 (In)

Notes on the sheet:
Bottom M2 holes
Screen M2 posts
u.FL to SMA-RP

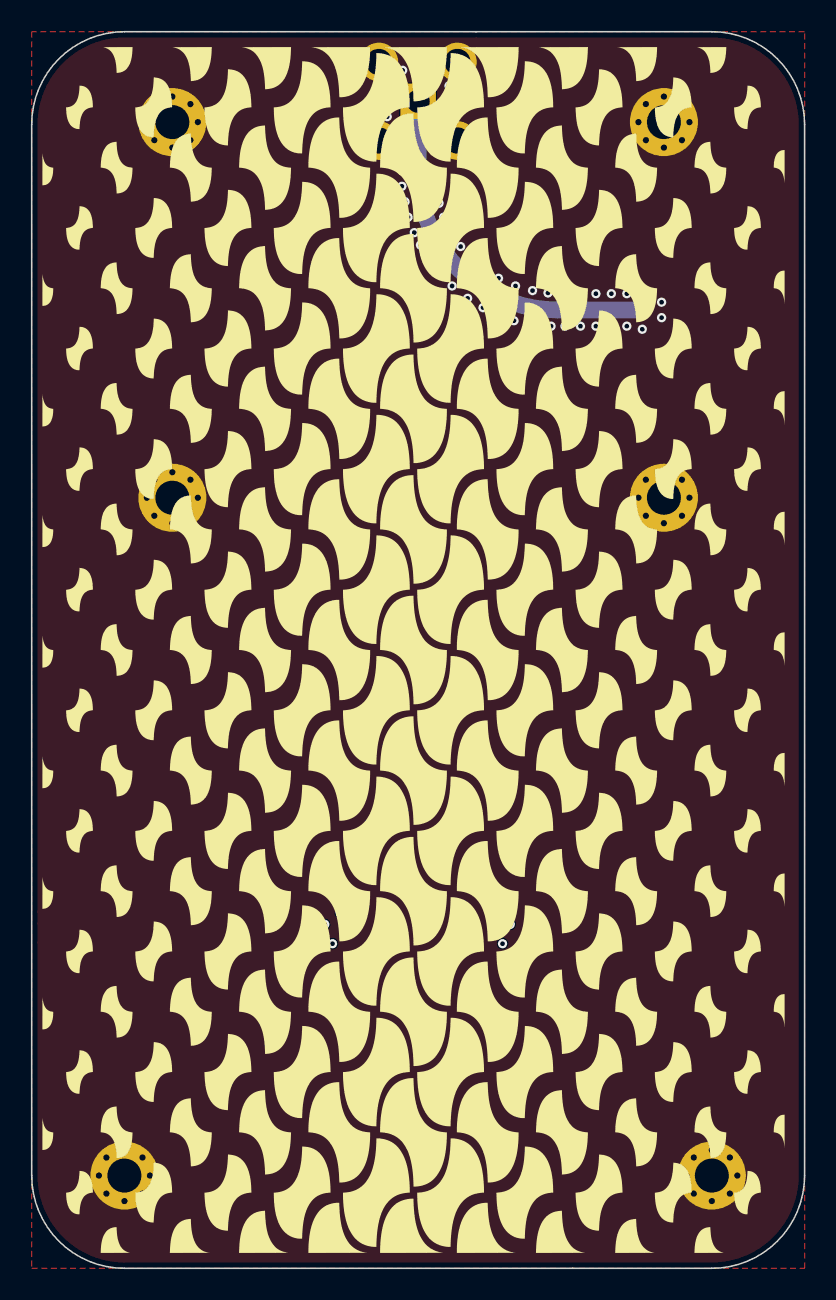
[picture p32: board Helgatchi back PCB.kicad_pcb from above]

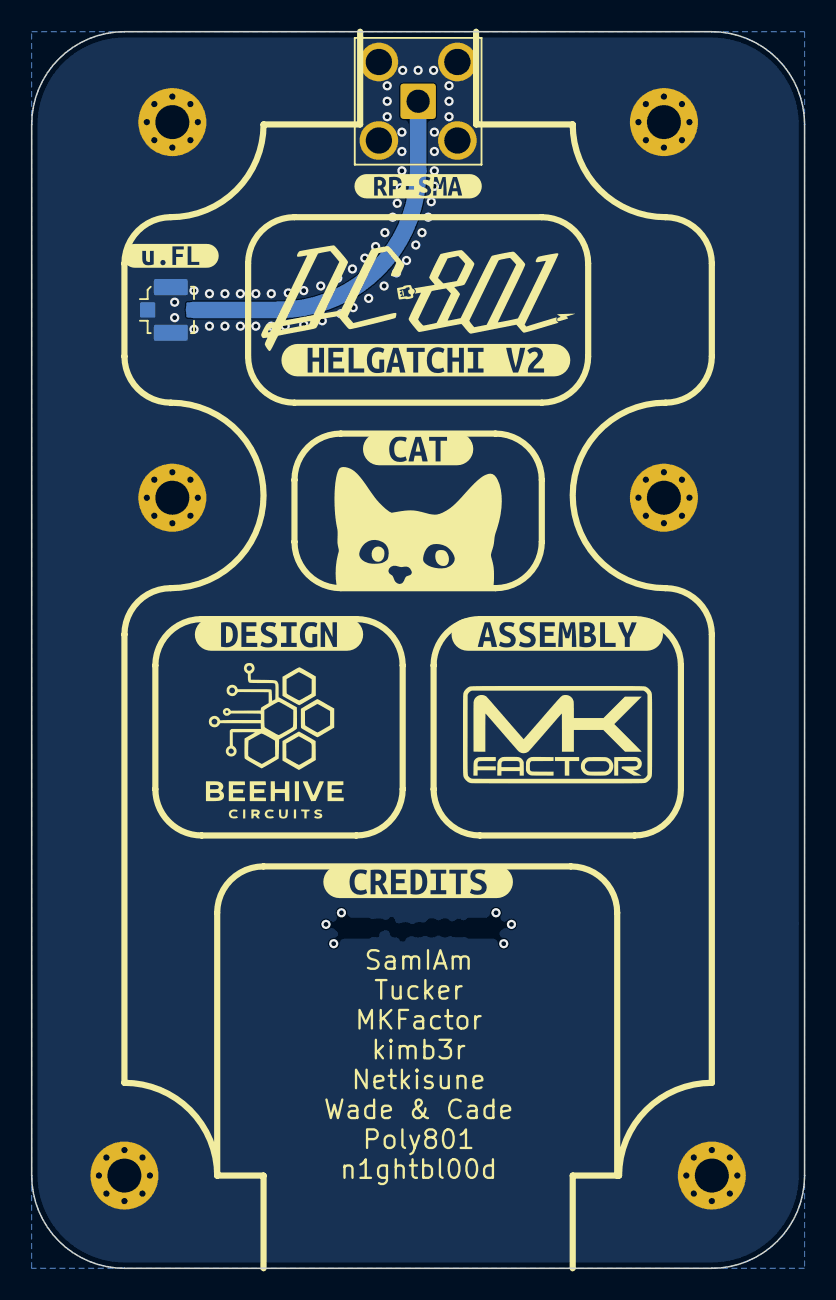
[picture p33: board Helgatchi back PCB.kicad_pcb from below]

Board: 2 copper layers, 50.0 x 80.0 mm, 15 parts (13 on the bottom side), 2 nets.

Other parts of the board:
kibuzzard-69B731C5: G***; kibuzzard-69B731C5
kibuzzard-69B731D4: G***; kibuzzard-69B731D4
kibuzzard-69B735E8: G***; kibuzzard-69B735E8
kibuzzard-69B7363E: G***; kibuzzard-69B7363E
kibuzzard-69B73206: G***; kibuzzard-69B73206
kibuzzard-69B73420: G***; kibuzzard-69B73420
kibuzzard-69B73430: G***; kibuzzard-69B73430

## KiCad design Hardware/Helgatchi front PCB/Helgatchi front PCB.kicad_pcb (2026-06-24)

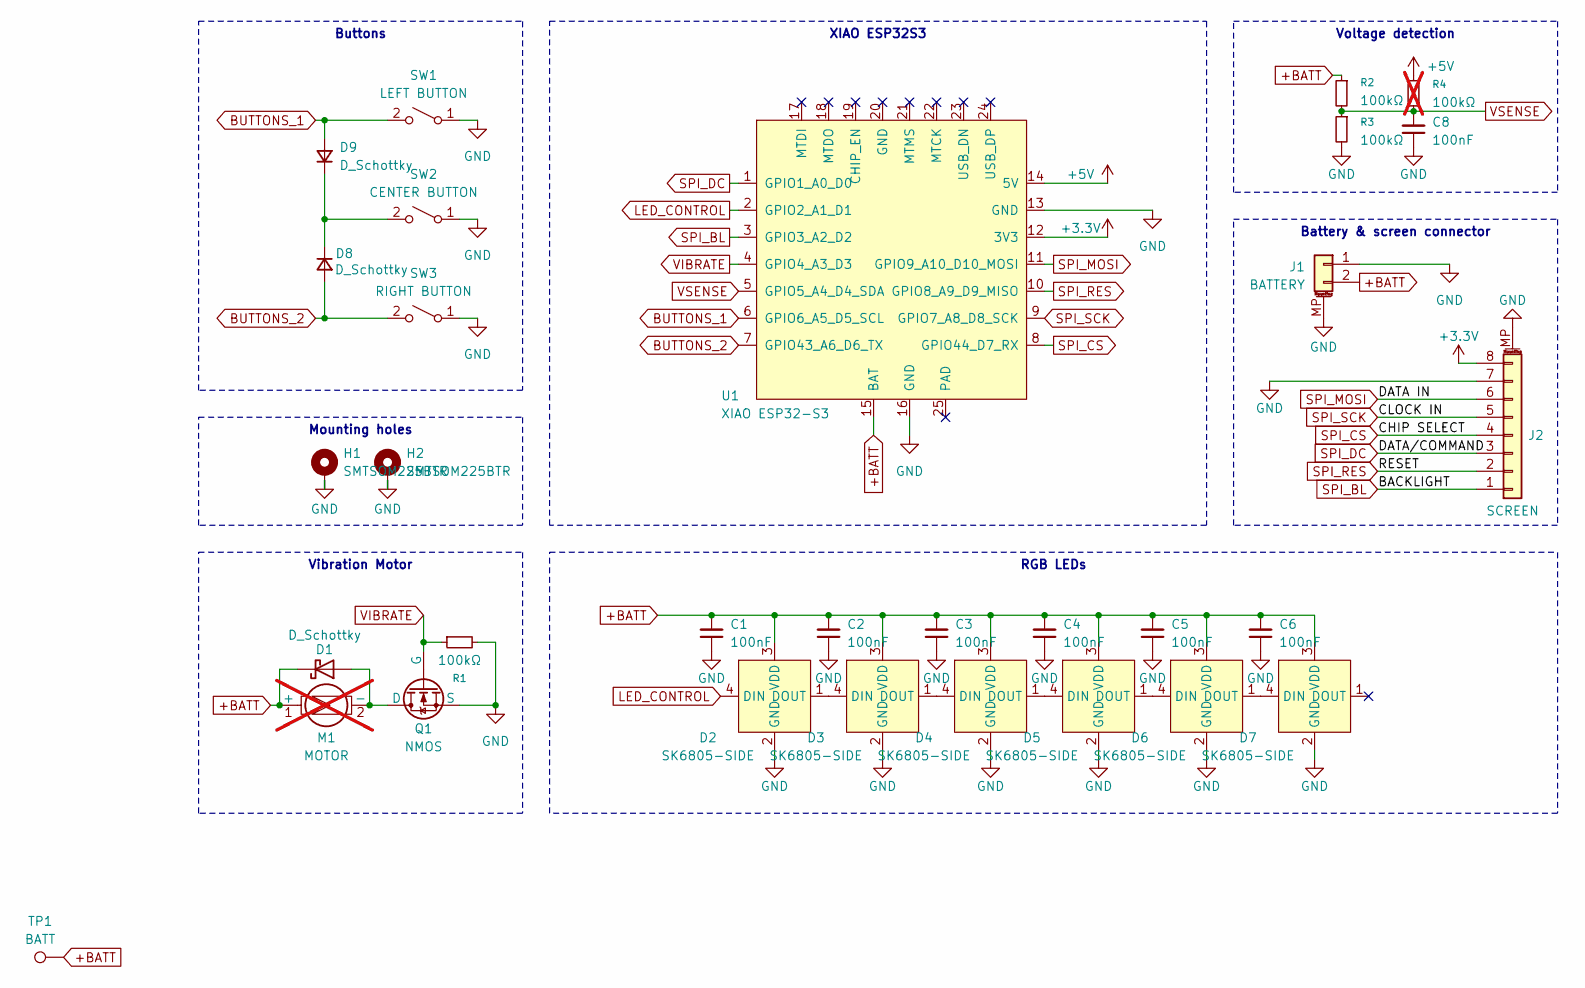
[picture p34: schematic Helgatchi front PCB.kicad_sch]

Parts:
C1, C2, C3, C4, C5, C6, C8: 100nF; C_0603_1608Metric; LCSC Part # C14663
D1, D8, D9: D_Schottky; D_SOD-523; LCSC Part # C7420320
D2, D3, D4, D5, D6, D7: SK6805-SIDE; LED-SMD_4P-L3.5-W1.6_SK6805SIDE-G-001; MPN SK6805SIDE-G-003; LCSC Part # C42417604
H1, H2: SMTSOM225BTR; SMD_BD5.6-D3.6; LCSC Part # C5301773
J1: BATTERY; JST_SH_SM02B-SRSS-TB_1x02-1MP_P1.00mm_Horizontal; LCSC Part # C160402
J2: SCREEN; Molex_PicoBlade_53261-0871_1x08-1MP_P1.25mm_Horizontal; LCSC Part # C7433459
M1: MOTOR; PinHeader_1x02_P2.54mm_Vertical; LCSC Part # C2682302; not fitted
Q1: NMOS; SOT-23; LCSC Part # C20917
R1, R2, R3: 100kΩ; R_0603_1608Metric; LCSC Part # C25803
R4: 100kΩ; R_0603_1608Metric; LCSC Part # C25803; not fitted
SW1: LEFT BUTTON; Reverse button footprint; LCSC Part # C9900250000
SW2: CENTER BUTTON; Reverse button footprint; LCSC Part # C9900250000
SW3: RIGHT BUTTON; Reverse button footprint; LCSC Part # C9900250000
TP1: BATT; TestPoint_Pad_D1.0mm
U1: XIAO ESP32-S3; XIAO-ESP32S3-SMD; LCSC Part # C9900124959

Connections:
+3.3V: J2.8, U1.12 (3V3)
+5V: R4.1, U1.14 (5V)
+BATT: C1.2, C2.2, C3.2, C4.2, C5.2, C6.2, D1.1 (K), D2.3 (VDD), D3.3 (VDD), D4.3 (VDD), D5.3 (VDD), D6.3 (VDD), D7.3 (VDD), J1.2, M1.1 (+), R2.1, TP1.1 (1_1), U1.15 (BAT)
BUTTONS_1: D9.2 (A), SW1.2 (B), U1.6 (GPIO6_A5_D5_SCL)
BUTTONS_2: D8.2 (A), SW3.2 (B), U1.7 (GPIO43_A6_D6_TX)
GND: C1.1, C2.1, C3.1, C4.1, C5.1, C6.1, C8.1, D2.2 (GND), D3.2 (GND), D4.2 (GND), D5.2 (GND), D6.2 (GND), D7.2 (GND), H1.1 (1_1), H2.1 (1_1), J1.1, J1.MP (MountPin), J2.7, J2.MP (MountPin), Q1.2 (S), R1.2, R3.2, SW1.1 (A), SW2.1 (A), SW3.1 (A), U1.13 (GND), U1.16 (GND)
LED_CONTROL: D2.4 (DIN), U1.2 (GPIO2_A1_D1)
unnamed: D1.2 (A), M1.2 (-), Q1.3 (D)
unnamed: D2.1 (DOUT), D3.4 (DIN)
unnamed: D3.1 (DOUT), D4.4 (DIN)
unnamed: D4.1 (DOUT), D5.4 (DIN)
unnamed: D5.1 (DOUT), D6.4 (DIN)
unnamed: D6.1 (DOUT), D7.4 (DIN)
unnamed: D8.1 (K), D9.1 (K), SW2.2 (B)
SPI_BL: J2.1, U1.3 (GPIO3_A2_D2)
SPI_CS: J2.4, U1.8 (GPIO44_D7_RX)
SPI_DC: J2.3, U1.1 (GPIO1_A0_D0)
SPI_MOSI: J2.6, U1.11 (GPIO9_A10_D10_MOSI)
SPI_RES: J2.2, U1.10 (GPIO8_A9_D9_MISO)
SPI_SCK: J2.5, U1.9 (GPIO7_A8_D8_SCK)
VIBRATE: Q1.1 (G), R1.1, U1.4 (GPIO4_A3_D3)
VSENSE: C8.2, R2.2, R3.1, R4.2, U1.5 (GPIO5_A4_D4_SDA)

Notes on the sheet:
XIAO ESP32S3
Buttons
RGB LEDs
Voltage detection
Vibration Motor
Battery & screen connector
Mounting holes

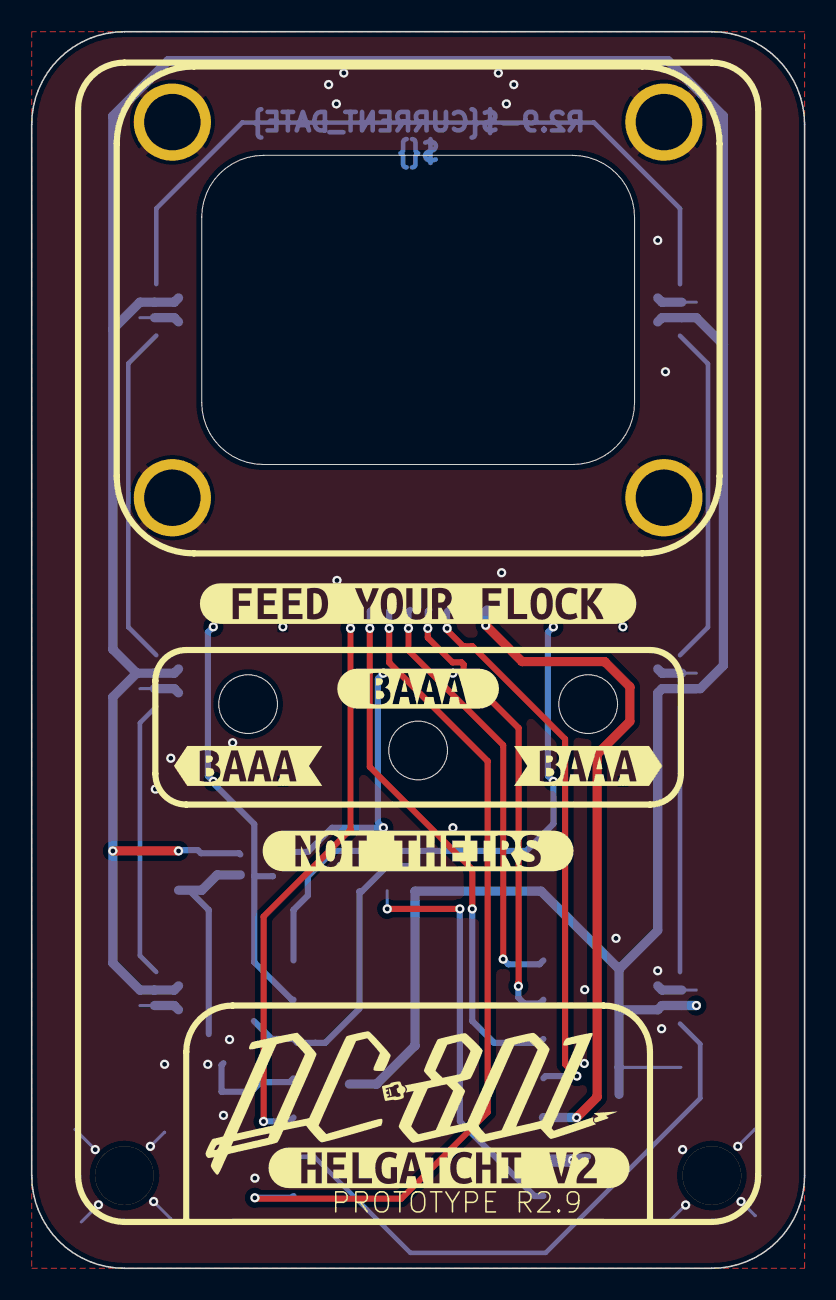
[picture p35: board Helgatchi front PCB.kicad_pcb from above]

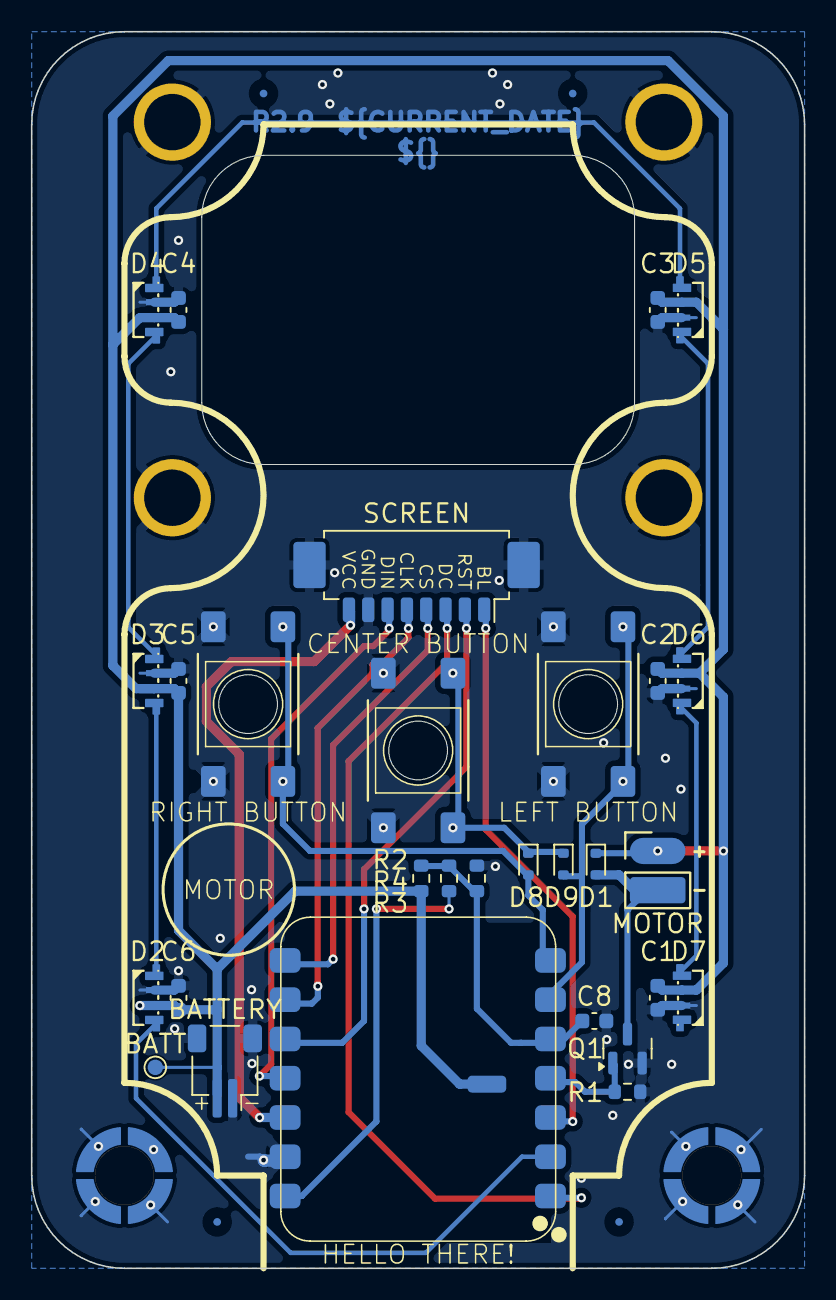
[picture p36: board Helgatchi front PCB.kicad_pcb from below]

Board: 2 copper layers, 50.0 x 80.0 mm, 38 parts (31 on the bottom side), 22 nets.

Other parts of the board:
Untitled: Waveshare 1.69"; Waveshare 1.69_
kibuzzard-6976EA3A: G***; kibuzzard-6976EA3A
kibuzzard-6976EA47: G***; kibuzzard-6976EA47
kibuzzard-6976EDA9: G***; kibuzzard-6976EDA9
kibuzzard-6976EEFC: G***; kibuzzard-6976EEFC
kibuzzard-6976EF0C: G***; kibuzzard-6976EF0C
kibuzzard-69862DFC: G***; kibuzzard-69862DFC

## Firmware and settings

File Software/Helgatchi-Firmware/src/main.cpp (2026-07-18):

#include <Arduino.h>
#include "event_bus.h"
#include "settings_service.h"
#include "hal.h"
#include "log_service.h"
#include "serial_console.h"
#include "power_manager.h"
#include "display_service.h"
#include "settings_screen.h"
#include "alerts_screen.h"
#include "devices_screen.h"
#include "foxhunting_screen.h"
#include "debug_screen.h"
#include "overview_screen.h"
#include "power_menu_screen.h"
#include "party_service.h"
#include "admin_service.h"
#include "ui_controller.h"
#include "led_service.h"
#include "vibe_service.h"
#include "alerts_service.h"
#include "scan_service.h"
#include "scan_engine.h"
#include "rules_service.h"
#include "perf_stats.h"
#include <LittleFS.h>
#include <esp_sleep.h>
#include <esp_system.h>

LoopPerf g_loop_perf;

static void _printBootInfo() {
    Serial.printf("[boot] chip:  %s rev%u  cores:%u\n",
                  ESP.getChipModel(), ESP.getChipRevision(), ESP.getChipCores());
    uint64_t mac = ESP.getEfuseMac();
    Serial.printf("[boot] mac:   %02X:%02X:%02X:%02X:%02X:%02X\n",
                  (uint8_t)(mac >> 40), (uint8_t)(mac >> 32), (uint8_t)(mac >> 24),
                  (uint8_t)(mac >> 16), (uint8_t)(mac >>  8), (uint8_t)(mac));
    Serial.printf("[boot] heap:  %lu B free\n",  (unsigned long)ESP.getFreeHeap());
    Serial.printf("[boot] flash: %lu KB\n",       (unsigned long)(ESP.getFlashChipSize() / 1024));
    Serial.printf("[boot] scan:  mode=%u  perf=%u  scan_s=%u  sleep_s=%u\n",
                  g_settings.get(SKEY_SCAN_MODE),   g_settings.get(SKEY_PERF_MODE),
                  g_settings.get(SKEY_SCAN_DURATION_S), g_settings.get(SKEY_SLEEP_DURATION_S));
    Serial.printf("[boot] vsense: %u mV\n", g_hal.readVsenseMv());
    Serial.printf("[boot] debug: level=%u  sleep_w_serial=%u\n",
                  g_settings.get(SKEY_DEBUG_LEVEL),
                  g_settings.getBool(SKEY_DEBUG_SLEEP_WITH_SERIAL));
}

void setup() {
    Serial.begin(115200);

    // EARLIEST: on a button wake from deep sleep (regular or shipping), verify
    // the user is holding CENTER long enough — otherwise re-enter the same
    // sleep without spinning anything else up. May not return. Timer wakes and
    // cold boots pass straight through.
    PowerManager::checkWakeHoldOrResleep();

    const uint32_t t0 = millis();
    while (!Serial && (millis() - t0) < 2000) { delay(10); }
    delay(200);

    g_bus.begin();
    g_settings.begin(g_bus);
    g_hal.begin(g_bus);
    g_logger.begin(g_bus);
    g_console.begin(g_bus);
    g_power.begin(g_bus);
    g_alerts.begin(g_bus); // must precede led/vibe so they can find() records when EV_ALERT_RAISED fires
    g_scan_service.begin(g_bus);          // ring buffer + seen-devices map
    g_scan_engine.begin(g_bus);   // NimBLE driver — publishes into g_scan_service
    // LittleFS must be mounted before RulesService reads /rules/factory and
    // /rules/user. formatOnFail=true so a fresh device with no FS image
    // still boots (it'll just find an empty filesystem).
    if (!LittleFS.begin(true /* formatOnFail */)) {
        Serial.println("[fs] FATAL: LittleFS mount failed — rules subsystem disabled");
    }
    g_rules.begin(g_bus);  // must follow LittleFS mount + g_scan_service + g_alerts
    g_leds.begin(g_bus);   // depends on HAL (LED chain) + bus events from PowerManager
    g_vibe.begin(g_bus);   // haptic patterns; subscribes to button + alert events
    g_ui.begin(g_bus);     // creates the LVGL display — auto-shows perf overlay
    g_logger.attachLvglLog(); // route LVGL logs to serial (Render debug level) — must follow lv_init
    g_display.begin(g_bus); // top-bar indicators — must follow g_ui (objects.* must exist)
    g_settings_screen.begin(g_bus); // settings widget wiring — must follow g_ui
    g_alerts_screen.begin(g_bus);   // alert cards UI — must follow g_ui + g_display + g_alerts
    g_devices_screen.begin(g_bus);  // device cards UI — must follow g_ui + g_scan_service
    g_foxhunting_screen.begin(g_bus); // foxhunt lock-on UI — must follow g_ui + g_scan_service + g_scan_engine
    g_debug_screen.begin(g_bus);    // diagnostics view — must follow g_ui
    g_overview_screen.begin(g_bus); // Helga character animation — must follow g_ui
    g_party.begin(g_bus);           // party mode — must follow g_ui + g_overview_screen (references objects.*)
    g_admin.begin(g_bus);           // admin mode — must follow g_scan_engine (BLE init + admin queue) + g_ui (objects.*)
    g_power_menu_screen.begin(g_bus); // power menu buttons + sleep countdown — must follow g_ui
    g_logger.applyPerfMonitor();   // re-hide unless level >= RENDERING_PERF

    if (g_settings.getBool(SKEY_DEBUG_SERIAL_ENABLED)) {
        _printBootInfo();
    }

    // Boot indicator: white LED flash + short haptic. Only fires for boots
    // the user *initiated* — fresh power-on, or button wake from deep sleep.
    // Software resets (Reboot button calling ESP.restart, panic, watchdog)
    // get NO indicator: the user just produced a haptic clicking the button
    // that triggered the reset, and a second haptic on the other side feels
    // like one long buzz. TIMER wakes (autonomous scan) also stay silent.
    {
        esp_sleep_wakeup_cause_t cause  = esp_sleep_get_wakeup_cause();
        esp_reset_reason_t       reset  = esp_reset_reason();
        bool show_indicator =
            (reset == ESP_RST_POWERON) ||
            (reset == ESP_RST_DEEPSLEEP && cause == ESP_SLEEP_WAKEUP_EXT1);

        if (show_indicator) {
            g_hal.setAllLEDs(30, 30, 30);
            if (g_settings.getBool(SKEY_ALERT_VIBRATION)) {
                g_hal.setVibrate(220);
                delay(60);
                g_hal.stopVibrate();
                delay(140);
            } else {
                delay(200);
            }
            g_hal.clearLEDs();
        }
    }

    Serial.println("[Helgatchi] boot OK");
}

void loop() {
    // Per-phase timing folded into g_loop_perf (worst tick per 1 s window). One
    // micros() read per phase — negligible — so it runs unconditionally;
    // LogService reports it only at DEBUG_PERF. See perf_stats.h.
    uint32_t _t = micros();
    const uint32_t _loop_start = _t;

    PERF_TIME(hal_us,     g_hal.tick());         // USB SOF (attach) detection — buttons + haptics run on their own esp_timers
    PERF_TIME(bus_us,     g_bus.dispatch());     // drain event queue and call all handlers (device-list rebuild runs here)
    PERF_TIME(console_us, g_console.tick());     // process any pending serial input
    PERF_TIME(power_us,   g_power.tick());       // scan/sleep cycle + battery sampling
    PERF_TIME(scan_us,    g_scan_engine.tick()); // drain NimBLE callback queue + publish to g_scan_service
    g_admin.tick();                              // drain + auth admin command frames; expire admin effects
    PERF_TIME(rules_us,   g_rules.tick());       // drain scan ring + match against loaded rules
    PERF_TIME(leds_us,    g_leds.tick());        // ~30 FPS LED pattern render (frame-skips internally)
    g_party.tick();                              // party mode: re-fire haptics, cycle banner colour, keep-awake (no-op when idle)
    PERF_TIME(ui_us,      g_ui.tick());          // lv_timer_handler — drives LVGL rendering
    // Haptics no longer tick here — VibeService runs its step machine on a
    // one-shot esp_timer, immune to loop-cadence stalls (see vibe_service.h).

    const uint32_t _loop_dt = micros() - _loop_start;
    if (_loop_dt > g_loop_perf.loop_us) g_loop_perf.loop_us = _loop_dt;
    g_loop_perf.iterations++;
}

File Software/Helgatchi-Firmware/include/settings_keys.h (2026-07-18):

#pragma once
#include <stdint.h>

// ---------------------------------------------------------------------------
// Supporting enums
// ---------------------------------------------------------------------------

enum PerfMode : uint8_t {
    PERF_PERFORMANCE = 0,  // near-continuous scan, long wake duration
    PERF_BALANCED,         // moderate duty cycle, default timeouts
    PERF_BATTERY_SAVER,    // long intervals, short windows, aggressive sleep
    PERF_DYNAMIC,          // runtime auto-adjustment based on battery level
    PERF_ALWAYS_ON,        // while charging: never sleeps, screen stays on, ~0 gap
                           // between scan windows. On battery: normal duty cycle
                           // (this mode is meant for external power).
    PERF_MODE_COUNT
};

enum ScanMode : uint8_t {
    SCAN_DISABLED = 0,
    SCAN_BLE_ONLY,
    SCAN_WIFI_ONLY,
    SCAN_BLE_AND_WIFI,
    SCAN_MODE_COUNT
};

enum ScreenBrightness : uint8_t {
    SCREEN_BRIGHTNESS_MIN = 0,    // dim but still legible — floor for the user
    SCREEN_BRIGHTNESS_LOW,
    SCREEN_BRIGHTNESS_MEDIUM,
    SCREEN_BRIGHTNESS_HIGH,
    SCREEN_BRIGHTNESS_MAX,
    SCREEN_BRIGHTNESS_COUNT
};

enum LEDBrightness : uint8_t {
    LED_BRIGHTNESS_LOW = 0,
    LED_BRIGHTNESS_MEDIUM,
    LED_BRIGHTNESS_HIGH,
    LED_BRIGHTNESS_MAX,
    LED_BRIGHTNESS_COUNT
};

enum DebugLevel : uint8_t {
    DEBUG_INFORMATIONAL = 0,
    DEBUG_HIGH,
    DEBUG_RENDERING_PERF,
    DEBUG_SCANNING_PERF,
    DEBUG_PERF,             // periodic (1 s) memory + scan-pressure + loop-timing telemetry (human-readable)
    DEBUG_TELEPLOT,         // periodic (1 s) Teleplot ">k:v" stream for live graphing
    DEBUG_LEVEL_COUNT
};

// ---------------------------------------------------------------------------
// Settings keys
//
// [USER]    — shown on Settings screen, user can change
// [DEBUG]   — only shown when debug menu is unlocked
// [DERIVED] — set automatically (by perf mode, build flags, or linked setting)
//             not shown in UI
//
// NOTE: The following debug screen items are ACTIONS, not stored settings.
//       They emit commands — see event_ids.h:
//         "Reset statistics"         → CMD_STATS_RESET
//         "Reset settings"           → CMD_SETTINGS_RESET_DEFAULTS
//         "Shipping mode sleep"      → CMD_POWER_SHIPPING_SLEEP
//         "Shipping mode reset+sleep"→ CMD_POWER_SHIPPING_RESET
// ---------------------------------------------------------------------------

enum SettingsKey : uint8_t {

    // --- Display ---
    SKEY_SCREEN_BRIGHTNESS = 0,     // [USER]    ScreenBrightness
    SKEY_LED_BRIGHTNESS,            // [USER]    LEDBrightness

    // --- Scanning ---
    SKEY_SCAN_MODE,                 // [USER]    ScanMode
    SKEY_SCAN_ACTIVE,               // [USER]    bool — active scan (solicit scan responses) vs passive
    SKEY_PERF_MODE,                 // [USER]    PerfMode

    // --- Alerts ---
    SKEY_ALERT_WAKE_SCREEN,         // [USER]    bool — alert wakes display
    SKEY_ALERT_VIBRATION,           // [USER]    bool
    SKEY_ALERT_LED,                 // [USER]    bool
    SKEY_ALERT_FOCUS,               // [USER]    bool — alert loads the Alerts screen (except while on Settings)

    // --- Power ---
    SKEY_SLEEP_WHILE_USB,           // [USER]    bool — allow sleep when USB attached (no serial)
    SKEY_VSENSE_5V_DIVIDER,         // [USER]    bool — HW has R4 (+5V→VSENSE) populated; changes VBATT math

    // --- Debug (gated by debug menu) ---
    SKEY_DEBUG_SERIAL_ENABLED,      // [DEBUG]   bool — USB serial debug output
    SKEY_DEBUG_LEVEL,               // [DEBUG]   DebugLevel
    SKEY_DEBUG_SLEEP_WITH_SERIAL,   // [DEBUG]   bool — allow sleep even when serial connected

    // Occupies the slot vacated by the removed [DERIVED] SKEY_SCREEN_TIMEOUT_S
    // (which was dead — nothing consumed it). Kept in place rather than appended;
    // SCHEMA_VERSION is bumped so the old value in this slot resets to default
    // instead of being misread as this bool.
    SKEY_SLEEP_WHILE_CHARGING,      // [USER]    bool — allow sleep while charging (default off = inhibit; peer to SLEEP_WHILE_USB / DEBUG_SLEEP_WITH_SERIAL)

    // --- Internal / derived (not shown in UI) ---
    SKEY_INTERACTIVE_TIMEOUT_S,     // [DERIVED] seconds of inactivity before sleep (resets on EV_UI_ACTIVITY)
    SKEY_SLEEP_DURATION_S,          // [DERIVED] seconds the device sleeps between scan cycles
    SKEY_SCAN_DURATION_S,           // [DERIVED] seconds to scan per wake cycle; tuned by perf mode

    SKEY_TUTORIAL_SHOWN,            // [INTERNAL] bool — cleared on first flash / shipping wake
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

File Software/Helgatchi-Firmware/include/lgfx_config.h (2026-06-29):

#pragma once
#include <LovyanGFX.hpp>

// ST7789 240x280 on SPI2 (GPIO matrix) for XIAO ESP32-S3.
// Backlight (GPIO3) is NOT configured here — HAL drives it via LEDC PWM.
class LGFX : public lgfx::LGFX_Device {
    lgfx::Panel_ST7789  _panel;
    lgfx::Bus_SPI       _bus;

public:
    LGFX() {
        {
            auto cfg        = _bus.config();
            cfg.spi_host    = SPI2_HOST;
            cfg.spi_mode    = 0;
            cfg.freq_write  = 80000000;
            cfg.freq_read   = 16000000;
            cfg.spi_3wire   = false;
            cfg.use_lock    = true;
            cfg.dma_channel = SPI_DMA_CH_AUTO;
            cfg.pin_sclk    =  7;
            cfg.pin_mosi    =  9;
            cfg.pin_miso    = -1;
            cfg.pin_dc      =  1;
            _bus.config(cfg);
            _panel.setBus(&_bus);
        }
        {
            auto cfg         = _panel.config();
            cfg.pin_cs       = 44;
            cfg.pin_rst      =  8;
            cfg.pin_busy     = -1;
            cfg.panel_width  = 240;
            cfg.panel_height = 280;
            cfg.offset_x     =  0;
            cfg.offset_y     = 20;  // ST7789 GRAM starts 20 rows into 320-row array
            cfg.readable     = false;
            cfg.invert       = true;  // flip if colors are inverted on your panel
            cfg.rgb_order    = false;
            cfg.dlen_16bit   = false;
            cfg.bus_shared   = false;
            _panel.config(cfg);
        }
        setPanel(&_panel);
    }
};

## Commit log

2026-01-23 more of initial commit
    [Helgatchi front PCB.kicad_pcb, Helgatchi front PCB.kicad_sch, XIAO-ESP32S3 v2.step]
2026-01-30 Add LVGL Helgatchi project and update Core UI BLE handling
    Introduces the new 'LVGL Helgatchi' PlatformIO project with initial structure, configuration, and example code. Updates 'Helgatchi Core' to refine BLE manufacturer name handling in the UI, adds LVGL 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
2026-02-01 Add architecture documentation for firmware design
    This document outlines the event/service architecture for the device firmware, detailing core services, public mesh behavior, and UI integration. It includes core concepts such as the Event Bus, Mess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
2026-02-05 Drawings and laser cutter files
    [Helgatchi back PCB.kicad_pcb, Helgatchi back PCB.kicad_sch]
2026-02-05 Symbols and LEDs
    [WS2812B-4020.STEP]
2026-02-05 Swap to WS2812B-4020-H2 Footprint variant
    [Helgatchi front PCB.kicad_pcb, Helgatchi front PCB.kicad_sch]
2026-02-05 Spacer changes
    [Helgatchi Spacer - antenna - standoffs.dxf, Helgatchi back PCB-User_Drawings.dxf]
2026-02-06 Back PCB changes
    [Helgatchi back PCB.kicad_pcb, Helgatchi front PCB.kicad_sch]
2026-02-06 Production files
    [Helgatchi back PCB-User_Drawings.dxf]
2026-02-06 LCSC part # changes
    - Changed MOLEX Picoblate part number out for generic picoblade
    - Added part number and adjusted DNP for ESP32-S3
    [Helgatchi front PCB.kicad_pcb, Helgatchi front PCB.kicad_sch]
2026-02-06 Silkscreen Adjustments
    [Helgatchi front PCB.kicad_pcb]
2026-02-06 Add fab polarity markings for diode
    [Helgatchi front PCB.kicad_pcb]
2026-02-06 Add SDM2U30CSP Diode footprint and swap on board
    [Helgatchi front PCB.kicad_pcb]
2026-02-06 R2.3
    updated version to cut through solder mask.
    [Helgatchi front PCB.kicad_pcb]
2026-02-06 Swap <baaa> for (baaa)
    [Helgatchi front PCB.kicad_pcb]
2026-02-06 Add via in pads for buttons
    [Helgatchi front PCB.kicad_pcb]
2026-02-11 Helgatchi front PCB: update to R2.5
    Bump PCB revision to R2.5 and apply small layout/text tweaks: adjust gr_text position, update render_cache label/date, add font thickness to silkscreen effects, and shift numerous silkscreen/graphics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
    [Helgatchi front PCB.kicad_pcb, Helgatchi front PCB.kicad_sch]
2026-02-11 Bump Helgatchi front PCB to R2.6
    Update KiCad board revision to R2.6 and apply minor footprint/silkscreen geometry adjustments (including PROTOTYPE silkscreen and render_cache updates dated 2026-02-11). Add production archives and b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
    [Helgatchi front PCB.kicad_pcb]
2026-03-15 R2.7
    - Shifted buttons up a tiny bit
    - Made room for the vibration motor to be adhered to the PCB
    - Enlarged vibration motor pads for easier hand soldering
    - Removed LED voltage selector (now 3.3v)
    - Removed unused pins from schematic and ESP32 footprint
    - Added a keepout area under ESP32
    - Replaced +BATT trace
    - Removed -BATT trace, tied to GND
    - Added keepout around button GND vias, to prevent heat soak during soldering
    - Scooted ESP back a little bit to make room for assembly
    - Adjusted front silkscreen
    - Swapped buttons to two GPIO Diode matrix
    - Added VSENSE + resistors and capacitor
    [Helgatchi front PCB.kicad_pcb, Helgatchi front PCB.kicad_sch]
2026-03-15 Update Helgatchi front PCB.kicad_pcb
    [Helgatchi front PCB.kicad_pcb]
2026-03-17 Update helgatchi spacer
    [7.6mm Spacer.step, 8.6mm Spacer.step, Spacer.FCStd]
2026-03-24 Update back PCB to R2.7
    [Helgatchi back PCB.kicad_pcb, Helgatchi back PCB.kicad_sch]
2026-03-24 Wrap up R2.7
    - Added voltage sensing
    - made room for Vibration buzzer
    - added SMD M2 nut
    - swapped flyback diode
    [Helgatchi front PCB.kicad_pcb, Helgatchi front PCB.kicad_sch]
2026-04-04 Front PCB drawings
2026-04-04 Front PCB r2.7 order
    [Helgatchi front PCB.kicad_pcb, Helgatchi front PCB.kicad_sch]
2026-04-04 Back PCB order
    [Helgatchi back PCB.kicad_pcb]
2026-04-04 Silkscreen pdf
2026-04-04 new spacers
    [7.6mm Spacer antenna cutout 2.5mm holes.step, 7.6mm Spacer antenna cutout 3mm holes.step, 8.6mm Spacer antenna cutout 2.5mm holes.step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]
2026-04-09 spacer updates
    [Helgatchi back PCB-User_Drawings.FCStd, Spacer.FCStd]
2026-04-09 update for screen post cutouts
    [Spacer.FCStd]
2026-04-09 Variable-defined spacer
    [Spacer.FCStd]
2026-04-09 Spreadsheet-defined spacer
    [Spacer.FCStd]
2026-04-09 bambu slicer stuff added
    [Conjoined Spacer.3mf, Conjoined Spacer.step]
2026-04-13 Start of R2.8
    - Moving to SK6805s for LEDs
    - imported footprint, symbol, and 3D model for SK6805-SIDE
    - updated footprints and symbols for LEDs
    - repositioned LEDs and capacitors
    - Swapped LED chain direction to accommodate easier routing with new pinout
    [Helgatchi front PCB.kicad_pcb, Helgatchi front PCB.kicad_sch]
2026-04-30 Wrap up R2.8
    Boards ordered, version locked
    [Helgatchi back PCB.kicad_pcb, Helgatchi front PCB.kicad_pcb]
2026-06-04 Commit new UI files
    [Helgatchi front PCB.kicad_pcb, Helgatchi front PCB.kicad_sch, Helgatchi test jig.kicad_pcb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]
2026-06-04 Add Devices screen
2026-06-04 Alerts and devices work
2026-06-24 final R2.9 revision, boards ordered
    [Helgatchi front PCB.kicad_pcb, Helgatchi front PCB.kicad_sch]
2026-06-29 Update to new firmware
    [Helgatchi back PCB.kicad_pcb, motorola.json]
2026-06-29 UI fixes and performance
    [serial_console.cpp]
2026-06-30 Alert page wired up, alert service created, serial commands added
2026-06-30 fix screen sleep issue
    [power_manager.cpp]
2026-07-02 Enhance deep sleep and alert focus behavior in firmware
    - Updated deep sleep handling to require a deliberate center button hold for wake.
    - Introduced a latch mechanism for alert focus to prevent mid-edit interruptions.
    - Improved serial console command handling for adding multiple criteria.
    - Adjusted button debounce logic to prevent false triggers during wake.
    [hal.cpp, main.cpp, power_manager.cpp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]
2026-07-04 update serial console, fix improv
    [serial_console.cpp]
2026-07-04 Added to rules set. Will add more later.
    [motorola_solutions.json]
2026-07-05 Battery 5v detection
2026-07-06 update devices screen
2026-07-06 initial devices code
2026-07-07 update devices page, testing for crashes
2026-07-07 improved devices view
2026-07-07 active scanning, ble address type, and fixed scan window
    [serial_console.cpp, settings_keys.h]
2026-07-07 setScanCallbacks duplicate frames off
2026-07-08 dirty rendering of devices screen + LVGL logging
2026-07-08 Fix vibration duration and button presses missing
    [hal.cpp, log_service.cpp, main.cpp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]
2026-07-08 fix battery sampling spiking
    [hal.cpp]
2026-07-08 Fix settings changing sppike (settings now save every 1m or on sleep/reboot/deepsleep)
    [power_manager.cpp]
2026-07-09 Update Helgatchi UI.eez-project
    Added 48 frames to Helga animations
2026-07-10 screen bumper
    [screen bumper stacked.3mf, screen bumper.step]
2026-07-11 Add power screen
2026-07-11 New power menu and new power call
2026-07-11 update power command
2026-07-11 add power action screen
2026-07-11 Allow for canceling power action
2026-07-11 fix power cancelation
2026-07-11 add force restart button to web flasher + logo
2026-07-15 add monitor filters
2026-07-17 device screen performance
2026-07-17 Device screen visual and performance improvments
2026-07-17 Update LED patterns, admin page, and add LED list
2026-07-18 Add devices count to title
2026-07-18 Update LEDs and bar graph for hunting
2026-07-18 Added new alerts and reformated the title so it doesn't clip under the dismiss button.
    [motorola_solutions.json]
2026-07-18 Fixed rules not firing alerts properly
    [rules_service.cpp, serial_console.cpp]
2026-07-18 Fix processing rule JSON files
    [rules_service.cpp]
2026-07-18 update rules engine to support regex
    [motorola_solutions.json]
